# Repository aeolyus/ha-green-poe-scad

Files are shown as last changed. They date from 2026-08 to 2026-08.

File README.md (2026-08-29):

# Home Assistant Green + TP-Link PoE Splitter — 10-inch 1U mount

GitHub Pages site: <https://aeolyus.github.io/ha-green-poe-scad/>

Designed for:

- DeskPi/GeeekPi RackMate T2 12U, 10-inch rack
- Home Assistant Green (official 112 × 112 × 32 mm nominal envelope; physical unit measured 111.13 mm across the bottom, 107.95 mm across the top plateau, and 33.34 mm tall)
- TP-Link TL-PD30G-M2 2.5G PoE+ splitter (80.8 mm published overall length; the revised physical measurements are a 67.47 × 48.42 mm top plateau, 53.98 mm maximum width, 24.61 mm total height, and an 18.26 mm straight side band)
- Bambu Lab X2D

The current user-selected first print is **rear cable entry, 60 mm cable-friendly splitter setback, bottom-aligned rounded vent-frame friction cages, two hollow lower box bridges, two sloped upper hollow-box ties, a plain front with no logo, an open LED viewing aperture, and integrated dovetail receivers with the gates optional**. Use `one_piece_rear_cable_friendly_unified_frame_dovetail_ready.3mf` or `.stl`; the separately printed gate plate is not required for the first fit check. The earlier no-upper-tie and no-dovetail files remain available as comparisons.

Smooth continuous tray walls target a light 0.10 mm-per-side friction fit around the physically measured 111.13 mm lower footprint, then follow the measured inward taper beginning 6.35 mm above the bottom and ending at the 107.95 mm top plateau. Low front/rear stops resist sliding without localized ribs, tabs, or clips. The original 3 mm ventilated honeycomb is translated upward so its top is the normal 9.025 mm device seating plane; the open space below replaces the former four riser columns without filling the tray solid. Annular lands preserve the optional factory screw-hole locations. The Green floor, TP-Link floor, and connecting bridge all share this height, and everything remains fused into the mount. Two hollow 8 mm-high box beams now replace the earlier one-sided L-flanges between the cages. Four longitudinal L-section rails continue the TP-Link cage's upper-left, upper-right, lower-left, and lower-right corners into the faceplate. Their horizontal flanges remain flush with the cage floor and roof, while their vertical flanges stay outside the device envelope. This edge-distributed frame resists sag and twist without center bars, raised internal ridges, permanent triangular braces, or cable-path interference. Any desired support beneath the splitter cage can instead be generated and removed by the slicer.

All device ports face the rear. The TP-Link splitter sits straight on the left with its POWER+DATA IN port toward the rack rear. Its cradle follows the enclosure's symmetric 2.78 mm top and bottom bevel traversals, maintains a conservative 0.05 mm-per-side fit through the profile, and uses four low corner stops that leave both connector centers open. Its LAN/DC outputs face the front internally, and both short jumpers route through the open lane between the two trays before reaching the Green's rear ports.

The front is solid, word-free, logo-free, and has no decorative vents. Its outside corners and exposed tray edges are rounded. Cooling remains open where it matters: the Green's top is unobstructed, the raised 15 mm-pitch Green honeycomb supports it directly, and the narrower splitter shelf uses a 10 mm-pitch honeycomb inside its friction walls. The exposed triangular tray braces remain removed.

The 15 mm Green pattern is in the same visual scale as the linked UCG-Fiber rack mount and slightly finer than the larger cells visible on the linked USW-Lite-8 PoE enclosure. The TP-Link uses smaller cells because its clear shelf width is only about 42 mm; repeating the 15 mm grid there would leave too few load-sharing junctions.

The interactive viewer retains the front-Ethernet, alternate support, logo, shutter, other retention, and ventilated-enclosure studies for comparison. They are not the selected production edition. The ventilated 1U chassis remains viewer-only and is off by default.

## LED window

The production face uses a clean open aperture so the Green's LEDs remain directly visible. It has no lens, actuator slot, rear shutter pocket, retainer, or moving blade. The 8 mm-high aperture is centered on the physically measured illuminated band: 3.175 mm (4/32 in) above the Green's bottom and 19.05 mm (3/4 in) below its top. Its horizontal center now follows the measured 111.125 mm enclosure body rather than the older clearance envelope. The earlier translucent insert and captive shutter remain optional comparison parts.

The former captive-shutter mechanism remains only as a clearly named optional comparison export and as a viewer toggle. Likewise, the optional logo study is not cut into the canonical plain face.

## Cable routing and length check

The interactive preview includes three non-printing cable mockups:

- Incoming PoE patch lead from the rack rear to TP-Link POWER+DATA IN
- Internal Ethernet jumper from TP-Link LAN OUT to the Green
- DC jumper from TP-Link DC OUT to the Green

The production splitter setback is not determined by the incoming PoE lead. Its LAN/DC outputs face the front, so the open space in front of the body gives ordinary straight molded plugs room to exit and turn into the center lane. Moving the splitter forward makes the mount shallower, but it lengthens both internal jumpers and tightens their bend radius.

The updated mockups use a conservative 25 mm external straight-RJ45 boot envelope, Ubiquiti's published 21 mm minimum bend radius for its current patch cable, a 22 mm straight DC plug envelope, and rounded cable turns. These are precomputed static clearance routes—not an interactive physics simulation—and are planning envelopes rather than exact geometry for every cable Richard owns.

The webpage compares three side-by-side rear-entry TP-Link placements, one bottom-aligned unified-frame study, one centered-stacked TP-Link study, three front-Ethernet editions, and one SICSOLINK cable-routing mockup:

- **Compact, 35 mm setback:** 32 mm / 1.26 in from the panel's inside face to the splitter, leaving about 7 mm / 0.28 in after the modeled 25 mm boot; the collision-aware orange mockups require approximately 3.7 mm Ethernet and 7.6 mm DC bend radii, so this remains a visual comparison
- **Balanced, 47.5 mm setback:** 44.5 mm / 1.75 in of inside clearance, leaving about 19.5 mm / 0.77 in after the modeled boot; Richard's actual flexible cable was comfortable at this spacing, although the conservative generic Ethernet mockup remains orange because it targets a larger 21 mm bend radius
- **Cable-friendly, 60 mm setback:** current printable layout; 57 mm / 2.24 in of inside clearance leaves about 32 mm / 1.26 in after the modeled boot, and separate cable lanes preserve the full 21 mm Ethernet and 10 mm DC bend radii
- **Bottom-aligned unified frame, 60 mm setback:** current user-selected print; both cages share the same floor, two hollow lower box bridges join their bases, and two sloped upper hollow-box ties join their unequal roof heights
- **Centered stacked:** viewer-only study with the Green centered on the panel and the TP-Link rotated 90° directly behind it; both sit on the 9.025 mm unified deck, the printed depth is 202.4 mm / 7.97 in, and the side-facing LAN port permits a full-radius R21 turn to the Green
- **Front Ethernet — center gap, 60 mm setback:** the jack sits between the plain left face area and LED window while three layered cable paths preserve the modeled bend radii without increasing printed depth
- **Front Ethernet — HA right, 60 mm setback:** the jack sits physically to the right of the Green, while a full-radius PoE route loops behind the devices; this is a one-piece-only edition because the keystone occupies the detachable right-ear joint zone
- **Front Ethernet — left, 89 mm setback:** alternate jack in the left face area; the splitter moves 29 mm rearward so the straight PoE jumper can rise over it safely
- **SICSOLINK rear-angle:** viewer-only comparison using the existing splitter's seller-stated 180 mm captive leads; the visible routes consume about 165–170 mm and leave roughly 10–15 mm tolerance

The collision-aware internal Ethernet routes are approximately 370 mm across the three TP-Link positions before service slack. A 0.3 m / 1 ft lead is too short once ordinary straight plugs and real bends are included. Use a 0.5 m / roughly 20-inch patch lead. Ubiquiti's current line offers 0.4 m rather than 0.5 m; that leaves little service slack, while a 1 m lead can be looped at the cable-management points.

The corresponding straight-DC routes are approximately 250–275 mm before service slack. A 10-inch lead is too tight for the shallower comparisons; 12 inches / 300 mm is the safe general target and is the likely range of the bundled TP-Link jumper based on the unboxing, though TP-Link does not publish its length. A right-angle DC cable is not required because the RJ45 remains the limiting connector.

For the incoming PoE lead from an adjacent patch-panel coupler, start with a 1 ft cable. Use 0.5 m if the patch panel is more than roughly one rack unit away or if you want a service loop; that run depends on the actual rack-unit spacing and is not assigned an exact length by the viewer.

Each optional front-entry edition needs one additional internal Ethernet jumper from the rear of its feed-through keystone to TP-Link POWER+DATA IN. The modeled tip-to-tip lengths and practical cable choices are:

| Front jack location | Keystone → TP-Link route | Practical cable | Other internal leads |
| --- | ---: | --- | --- |
| Center gap | about 331 mm | 0.4 m minimum; 0.5 m preferred | TP-Link LAN → Green is about 356 mm, so use 0.5 m. DC is about 286 mm; 300 mm is possible but tight, and 350 mm is safer. |
| HA right | about 349 mm with the full 21 mm RJ45 bend | 0.4 m minimum; 0.5 m preferred | Uses the cable-friendly 60 mm splitter-to-Green lanes: use 0.5 m Ethernet and approximately 300–350 mm DC. |
| Left | about 266 mm | 0.4 m minimum; 0.5 m preferred | Use 0.5 m Ethernet and approximately 300 mm DC so ordinary straight plugs retain service slack. |

The center-gap cable envelope reaches about 213.6 mm rack depth; the left reaches about 218.3 mm, both within the T2's nominal 240 mm envelope. The HA-right route also remains within that envelope but deliberately makes a broad rear loop instead of forcing a tight turn. All three editions need a standard Cat6/6A female-to-female keystone coupler. Print `keystone_fit_test.stl` first because latch and body dimensions vary slightly between vendors.

For this rack, rear entry is the selected production layout: it keeps the front visually clean, uses one fewer coupler and internal cable, and gives simpler service access from the patch-panel side. Front entry remains useful as a comparison if you expect frequent troubleshooting or want to repatch without reaching behind the rack.

TP-Link lists a power cord in the box, and an independent unboxing clearly shows a male-to-male barrel jumper. TP-Link does not publish its exact length, barrel dimensions, or polarity. Try that supplied straight lead first. Before connecting the Green, set the selector to 12 V and verify both fit and center-positive polarity with a meter. If a replacement is needed, use a verified 12-inch straight-through lead whose Green end is 5.5 × 2.1 mm and whose current rating is at least 2 A.

Status: both rounded-cage device fits are physically validated as snug. The user-selected bottom-aligned unified-frame STL is closed two-manifold geometry and Bambu Studio reports it as manifold; its new upper ties still need this first full physical print. `assembly.stl` remains a multi-body reference file rather than a print target. The optional dovetail gate remains coupon-gated and does not need to be printed for the first fit check.

## Interactive preview

Open `viewer/interactive_viewer.html` through the included static-site layout and choose the splitter, side-by-side or centered-stacked arrangement, rear/front Ethernet entry, applicable spacing or front-jack position, retention, and optional protection. Those decisions map to nine modeled layouts: Compact, Balanced, Cable-friendly, Bottom-aligned unified frame, Centered stacked, Front–center gap, Front–HA right, Front–left, and the angled SICSOLINK cable example. Centered stacked and SICSOLINK are viewer-only studies. You can rotate, zoom, or jump between front, rear, top, perspective, retention-detail, and LED-window views. The hosted copy loads sibling GLBs to keep the initial HTML near 1 MB; `scripts/build.sh html` can regenerate an embedded single-file offline copy. Both forms record selections in the URL hash so a configuration can be bookmarked or shared.

The default view matches the active print: TP-Link, rear Ethernet, 60 mm cable-friendly setback, the bottom-aligned unified cage frame, integrated dovetail receivers with the gates optional, open trays with no chassis, no logo, no shutter hardware, visible simulated LEDs, and auto-rotation off. The comparison controls can still show the alternate supports, logo, captive shutter, front-entry layouts, other retention studies, and ventilated chassis. Those toggles do not change which files are canonical.

The **Retention** controls compare the selected integrated friction tray with the earlier M3-screw baseline and other studies. **Hybrid top clips · Green + PoE** keeps the Green's fixed/releasable catch arrangement, while the TP-Link now uses four mirrored rigid catches grown directly from continuous mini walls with no relief cuts or spring tongues. **Rounded vent-frame cages · Green + PoE** is the current aesthetic prototype preference: a rear-loading design inspired by the UCG-Fiber, USW-Lite, and Mauker Chromebox enclosure patterns, with honeycomb floors and 1.6 mm roofs meeting thick rounded side frames around one long capsule vent beside each device. The front stops remain and the rear stays open for insertion and cabling. Both cages keep one snug profile from front to rear, with square rear seams so their roofs, floors, and walls finish flush. Physical coupons now validate a snug fit for both devices: the Green uses 0.30 mm side and 0.10 mm roof clearance, while the TP-Link uses its proven 0.10 mm side and 0.05 mm roof clearance. The Green roof finishes at 44.0625 mm—0.3875 mm below the exact 44.45 mm panel top. **Vent-frame cages + padless dovetail gates** adds separately printed optional rear H-gates while retaining the same friction-fit cages as the primary retention. Their straight vertical tracks are buried inside locally thickened rear sidewall ends, and each H-frame seats in a matching shallow pocket so its rear face finishes flush with the cage. One smooth beveled lower beam replaces the former individual pads and sits 0.05 mm behind the device's solid lower rear face. A thin 0.8 mm stepped cap covers the gate pocket and beam-travel opening from above, leaving only a 0.02 mm separation so the roof reads as continuous while the gate remains a separate printable part. The central connector field remains open. The final 7 mm of rail travel wedges to a nominal line fit so the gate does not lift freely. Disconnect rear cables before sliding a gate. The gates need approximately 38 mm above the Green and 25 mm above the TP-Link during installation/removal, so service them before mounting another rack unit immediately above. The complete dovetail-ready one-piece mount and a separate two-gate plate are exported, but the gate sliding fit remains coupon-gated and physically unvalidated. The rounded cage dimensions themselves are already physically validated.

The support selector switches among four complete, mutually exclusive friction-tray meshes without reloading the GLB. **Unified raised deck** is selected: it lifts the original thin 3 mm honeycomb directly to the seating plane and leaves the volume below open. **Four pads** retains the earlier low floor and four raised lands; **Full honeycomb** fills the complete lattice and perimeter up to the seating plane; **Open frame** replaces the floor with a perimeter, two transverse load paths, a center spine, and four lands. Every version includes the same fused friction walls and low stops, with the rear center open for ports and cable service.

The comparison models do not replace tolerance coupons, material-specific clearance tuning, or a physical pull/rattle test. The unified raised-deck geometry is printable but still needs that physical validation because this is a new design.

The **Optional protection** control compares the default open tray with a ventilated full-width 1U chassis. The chassis adds a removable perforated top-and-side cover plus a low guide frame, enclosing the complete assembly while keeping the rear open for cables. With the exact 44.45 mm panel height, its 0.8 mm roof underside retains 1.0875 mm nominal clearance over the measured Green. It remains viewer-only until the enclosure assembly and cable access are physically validated. The chassis control is disabled for the above-device captive-strap, X-cage, and ventilated-sleeve concepts because those mechanisms consume the same roof space. It is off in existing links unless `protection=airframe` is selected.

### Static browser customizer

`customizer/index.html` provides a guided static-site configurator with the
interactive 3D model embedded beside the controls. When served
over HTTP(S), it lazily loads a vendored OpenSCAD WebAssembly worker, generates
the selected geometry locally, validates the binary STL, and offers both STL
and deterministic geometry-only 3MF downloads. From this directory, run
`python3 -m http.server 8000`, then open
`http://localhost:8000/customizer/`. Configuration and preset export still
work when the HTML file is opened directly, but browsers block module workers
under `file://`. Review `customizer/vendor/README.md` before public distribution
of the experimental GPL-2.0 runtime.

The cable models use straight—not right-angle—RJ45 and DC plugs. Orange internal cables identify bend-radius violations; normal blue/black cables meet the modeled envelope. When visible, the window simulates the Green's steady white power light, irregular green activity, and a two-flash yellow heartbeat; timing is illustrative rather than a diagnostic code. Gold three-dimensional rulers use 10 mm ticks, and a compact viewport overlay labels the exact 254 mm panel width, exact 44.45 mm / 1.750 in panel height, layout-specific printed depth, and panel-to-splitter clearance in both millimeters and inches. The viewer depicts the one-piece faceplate, so it has no detachable-ear joining bosses. Each of the nine layouts has two GLBs—shutter comparison and open-window/no-shutter—for 18 primary comparison models. Every applicable GLB contains the standard tray, all four mutually exclusive friction-tray meshes, the other retention overlays, and its layout-specific optional airframe at the same normal Green/LED coordinates, so switching retention, support style, or protection does not reload or reposition the model. The side-by-side TP-Link layouts include the dovetail prototype; the incompatible centered-stacked and SICSOLINK layouts disable it. The no-shutter GLBs omit the insert and shutter meshes entirely, leaving the bare aperture. `viewer/home-assistant-green-rack-preview.glb` is the cable-friendly open-window alias; `viewer/home-assistant-green-rack-preview-no_shutter.glb` is retained for compatibility, and `viewer/home-assistant-green-rack-preview-with_shutter.glb` is explicit.

The colored Home Assistant Green, TP-Link splitter, connector faces, and cables in these preview files are dimensional mockups only and are not part of the printable plate.

The viewer is a hand-built HTML page using Google's open-source `<model-viewer>` web component (which uses Three.js internally). Python and `trimesh` assemble the colored GLBs from OpenSCAD exports. The local offline build can embed those GLBs directly; `scripts/prepare_static_site.py` rewrites them to relative URLs for faster GitHub Pages loading.

## Parts

- `one_piece_rear_cable_friendly_unified_frame_dovetail_ready.stl` / `.3mf` — current user-selected one-piece print: bottom-aligned validated friction cages, two hollow lower bridges, two sloped upper hollow-box ties, and integrated receivers for optional separately printed dovetail gates
- `one_piece_rear_cable_friendly_unified_frame_no_dovetail.stl` / `.3mf` — the same tied cage frame without the optional dovetail receiver geometry
- `one_piece_rear_cable_friendly_vent_frame_no_dovetail.stl` / `.3mf` — earlier one-piece comparison with the physically validated rounded Green and TP-Link cages but no sloped upper ties or dovetail hardware
- `one_piece_rear_cable_friendly_vent_frame_dovetail_ready.stl` / `.3mf` — one-piece 254 mm-wide mount with the same friction cages plus integrated rear dovetail receivers; the devices remain friction-retained when no gates are installed
- `dovetail_gates_optional_plate.stl` / `.3mf` — optional second print containing the Green and TP-Link rear gates, both already resting on their broad rear faces
- `x2d_plate_rear_cable_friendly_vent_frame_no_dovetail.stl` / `.3mf` — safer split alternative containing the vent-frame core and both detachable ears as three faceplate-down objects
- `core.stl` — canonical split-core mount: rear entry, unified raised friction deck, plain face, and open LED aperture
- `one_piece.stl` / `.3mf` — the same canonical mount as one 254 mm-wide part, without detachable ears or rear joining bosses
- `x2d_plate.stl` / `.3mf` — canonical split core and both ears nested for the X2D dual-nozzle area
- `left_ear.stl` / `right_ear.stl` — detachable rack ears for `core.stl`
- `led_insert_optional.stl` and `led_fixed_window_kit_optional.stl` / `.3mf` — optional self-retaining translucent insert comparison
- `friction_fit_coupon.stl` / `.3mf` — regenerated smooth-wall channels at 0.25, 0.30, and 0.35 mm interference per side around the newly measured 111.125 mm bottom. The earlier near-perfect result used the superseded 109.5375 mm estimate and is no longer valid; test these in order and use the first one that holds without scuffing.
- `green_hybrid_clip_coupon.stl` / `.3mf` — one compact full-height Green spring-catch gauge. Its smooth single-piece profile follows the measured taper into a 1.4 mm bearing land with 1.2 mm nominal top overlap, a 0.8 mm shoulder, and a 0.4 mm leading tip. With the revised physical height it reaches 43.89 mm, leaving about 0.56 mm below the exact 44.45 mm panel top; add a 5 mm slicer brim.
- `splitter_fit_coupon.stl` / `.3mf` — three short open-ended smooth-wall test channels at 0.00, 0.05, and 0.10 mm interference per side for the TP-Link body; use the least aggressive level that holds before committing to its full-length friction cradle
- `splitter_hybrid_clip_coupon.stl` / `.3mf` — one compact open-frame TP-Link section with four-way-symmetric rigid ramps grown directly from continuous side walls, 1.4 mm bearing lands, 1.2 mm nominal top overlap, zero nominal top gap, 0.8 mm shoulders, and 0.4 mm leading tips; use it to confirm that the complete wall can flex enough for installation before printing the rack
- `hybrid_clip_coupon.stl` / `.3mf` — the single print containing both compact top-clip gauges, about 9.7 g of PETG total; regenerate or re-download it whenever the clip geometry changes
- `green_vent_frame_coupon.stl` / `.3mf` and `splitter_vent_frame_coupon.stl` / `.3mf` — separate 5 mm-deep solid rear perimeter bands from the exact rounded Green and TP-Link cages. The Green coupon keeps its accepted height and now has 0.30 mm clearance on each side; the TP-Link keeps its prior side fit and lowers only the flexible roof by 0.05 mm. At this depth the crop ends before the floor, roof, or side-wall honeycomb openings begin, and both parts are already oriented with their insertion faces on the build plate.
- `vent_frame_coupon.stl` / `.3mf` — the recommended low-material rounded-cage fit test containing both production-derived solid bands as separate objects; approximately 184.3 × 38.04 × 5 mm and 7.4 g of PETG by mesh volume
- `dovetail_rail_coupon.stl` / `.3mf` — a six-piece rail-and-H-gate clearance test for the viewer-only dovetail retention branch. One, two, and three marker holes identify 0.00, 0.05, and 0.10 mm final-wedge clearances; validate sliding, seated grip, and deliberate removal before considering a complete gated mount.
- `assembly.stl` — reference assembly only; print the separate parts above
- `fit_test.stl` / `.3mf` — general device-clearance check

Clearly named optional exports:

- `*_legacy_screw_tray.*` and `green_spacer*_legacy_screw_tray.*` — prior four-screw Green tray fallback
- `core_with_logo.*`, `one_piece_with_logo.*`, `x2d_plate_with_logo.*`, `logo_inlay_optional.stl`, and `one_piece_logo_inlay_optional.stl` — optional branded-face study; the inlay only fits a matching `_with_logo` mount
- `core_with_shutter.*`, `one_piece_with_shutter.*`, `x2d_plate_with_shutter.*`, and `led_shutter_*_optional.*` — optional captive-shutter study
- `*_front_ethernet_right.*`, `*_front_ethernet_left.*`, and `one_piece_front_ethernet_far_right.*` — optional front-entry comparisons, all otherwise inheriting the unified-raised-deck/plain-face/open-aperture defaults
- `keystone_fit_test.stl` / `.3mf` — front-keystone latch coupon
- The HA-right front-entry comparison is one-piece-only because its keystone occupies the detachable right-ear joint zone

Viewer and render artifacts:

- `renders/assembly_preview.png` — layout preview with translucent device mockups
- `viewer/home-assistant-green-rack-compact.glb` — 35 mm setback comparison mockup
- `viewer/home-assistant-green-rack-balanced.glb` — 47.5 mm setback comparison mockup
- `viewer/home-assistant-green-rack-unified_roof-no_shutter.glb` — GLB used by the production-default viewer state
- `viewer/home-assistant-green-rack-stacked_center.glb` — viewer-only centered Green with a transverse TP-Link directly behind it
- `viewer/home-assistant-green-rack-front_ethernet_right.glb`, `viewer/home-assistant-green-rack-front_ethernet_far_right.glb`, and `viewer/home-assistant-green-rack-front_ethernet_left.glb` — center-gap, HA-right, and left front-keystone mockups with their internal cabling
- Every viewer layout has both a shutter comparison GLB and a paired `-no_shutter.glb` bare-aperture GLB with no lens mesh
- `viewer/home-assistant-green-rack-front_ethernet.glb` and its no-shutter counterpart are compatibility aliases of the center-gap GLBs
- `viewer/home-assistant-green-rack-sics_angled.glb` — viewer-only angled SICSOLINK mockup showing its captive cable routing
- `viewer/viewer_green_tray_friction_raised.stl`, `viewer/viewer_green_tray_friction_pads.stl`, `viewer/viewer_green_tray_friction_full.stl`, and `viewer/viewer_green_tray_friction_skeletal.stl` — mutually exclusive complete friction-tray meshes for Unified raised deck, Four pads, Full honeycomb, and Open frame support; each includes the fused walls and stops
- `viewer/viewer_retention_hybrid_clips.stl` — viewer-only combined prototype containing the complete four-pad Green top-clip tray plus TP-Link replacement side walls with four mirrored rigid catches
- `viewer/viewer_retention_ventilated_sleeves.stl` — layout-specific rear-loading sleeve study with aligned raised honeycomb floors and thick rounded side frames around large capsule vents; no riser columns, springs, or relief slots
- `viewer/variants/*/viewer_enclosure_airframe.stl` — viewer-only ventilated 1U chassis study; it is not part of the printable production files

The selected one-piece vent-frame file is 254 × 44.45 × 143.7 mm in its supplied faceplate-down orientation and is approximately 120 g by PETG mesh volume. It nominally fits the X2D's 256 mm main-nozzle area with only 1 mm per side; center it carefully and do not use a brim. The X2D profile gives nozzle 1 the full X=0–256 mm area and nozzle 2 the X=20.5–256 mm area. Therefore the complete part does not need to fit inside the 235.5 mm overlap when nozzle 2 is used only for localized support interfaces: the PoE/bridge region sits at approximately X=28–88 mm on a centered plate and remains reachable by both nozzles. Keep the PETG model on nozzle 1 and any PLA support interface on nozzle 2. The safer split vent-frame plate is 220 × 94.45 × 143.7 mm, contains three objects, and is approximately 130 g because of the ear-joining bosses. The printed mount and modeled cable exits stay within the RackMate T2's approximately 240 mm internal depth.

## Hardware

- 4 × M3 × 8 mm screws for attaching the ears to the center section (preferred; M3 × 10 mm can work but leaves less front skin)
- 4 × #10-32 × 5/16 rack screws supplied with the RackMate T2
- Optional small zip ties for the short internal DC/LAN cable-management slots only; there are no Green-device zip-tie slots
- Any front-entry edition: 1 × Cat6/6A female-to-female keystone coupler and 1 × 0.5 m internal Ethernet patch cable

The Green needs no mounting screws in the selected friction tray; leave its factory bottom screws untouched. The M3 × 8 screws enter from the rear and only join the optional printed ears to the printed center. They self-tap into 2.6 mm pilot holes, so do not overtighten. They and the rear joining bosses are absent from `one_piece.stl`. The T2's pre-threaded rack rails officially use #10-32 screws, not M6 cage-nut hardware.

## Suggested print settings

- Material: white PETG (preferred) or ASA
- Layer height: 0.20 mm
- Walls: 4
- Top/bottom shells: 5
- Infill: 25–30% gyroid
- Supports: none for the core; use build-plate-only support beneath the two rear tongues on each ear
- Print `core.stl` faceplate-down: rotate it so the broad front face lies on the build plate. The raised decks then grow edge-on from the panel instead of beginning 6.025 mm above the bed.
- The selected `one_piece_rear_cable_friendly_unified_frame_dovetail_ready` files are already faceplate-down. Center the part and do not add a brim. Use nozzle 1 for the PETG model. The lower boxes and upper ties each begin as a roughly 16 mm bridge between already-established cage walls; PETG should normally bridge that distance, but the X2D can use localized PLA support interfaces there if your preview flags them. The support region remains inside nozzle 2's X=20.5–256 mm reach.
- The same orientation applies to optional comparison mounts and the HA-right one-piece file
- Ear and LED-insert STLs are already exported face-side down; enable support for the ear tongues

The supplied 3MF is geometry-only, not a pre-sliced Bambu project. In Bambu Studio, split it into objects and use normal/snug build-plate-only support on the ears rather than broad tree supports. A brim is normally unnecessary; a wide brim may join the nested pieces.

The production LED window is intentionally left open, so there is no lens, shutter blade, or retainer to print or assemble. The optional translucent insert can still be generated for comparison if dust protection is preferred later.

For the current friction baseline, print `friction_fit_coupon.stl` and `splitter_fit_coupon.stl`. If top clips are preferred, print only `hybrid_clip_coupon.stl` or `.3mf`; it places the selected Green and TP-Link gauges together without joining their roots. Use PETG or ASA, 0.20 mm layers, and 4–5 walls. Print the Green gauge tray-down with a 5 mm brim; orient the TP-Link gauge on its open Y/end face so its layers match the intended faceplate-down production print. The TP-Link coupon intentionally has no spring slots: tuck one edge under its rigid catches, then rock the opposite edge into place and confirm the continuous walls flex without whitening or cracking.

The rounded vent-frame coupons have now passed physically for both devices. Print the complete no-dovetail mount using the same printer, material, wall count, and dimensional-compensation settings as those successful coupons. The completed mount still needs a first-article pull/rattle check because its full-length cages are stiffer than the 5 mm gauges.

## Electrical safety

Home Assistant Green requires 12 V DC, 1 A, center-positive through a 5.5 × 2.1 mm barrel connector. The TP-Link provides selectable 12/9/5 V at up to 2 A and must be set to 12 V before any cable is connected. TP-Link does not publish the included cord's barrel dimensions or polarity, so verify center-positive output before connecting it to the Green; reverse polarity or the wrong selector setting can damage the Green.

## Purchase list and observed price

- [TP-Link TL-PD30G-M2](https://www.amazon.com/dp/B0F4CR925P) — $19.99 observed on 2026-08-25; includes the power cord
- Existing 0.5 m / roughly 20-inch UniFi or Monoprice patch cable for TP-Link LAN OUT → Green; 1 ft is too short with ordinary straight plugs
- Existing 1 ft patch cable for an adjacent PoE patch-panel coupler → TP-Link POWER+DATA IN; use 0.5 m for a larger RU separation or service loop
- 4 × M3 × 8 mm screws for the printed ears, if not already on hand

For the recommended rear-entry edition, no extra keystone coupler is required when the existing patch panel already has PoE-capable feed-through couplers. With existing patch cables and RackMate screws, the new electrical hardware total is $19.99 plus tax. Any optional front-entry edition adds the price of one female-to-female keystone and a 0.5 m internal jumper. A separate PoE injector is not needed when the source is already a standards-compliant PoE/PoE+ switch port.

## Source and export

The parametric source is `ha_green_rack.scad`. Example exports:

```sh
# Canonical production geometry inherits the source defaults.
openscad -o exports/core.stl -D 'part="core"' ha_green_rack.scad
openscad -o exports/one_piece.stl -D 'part="one_piece"' ha_green_rack.scad
openscad -o exports/x2d_plate.stl -D 'part="x2d_plate"' ha_green_rack.scad
openscad -o exports/led_insert_optional.stl -D 'part="led_insert"' -D 'led_window_insert_enabled=true' ha_green_rack.scad
openscad -o exports/friction_fit_coupon.stl -D 'part="friction_fit_coupon"' ha_green_rack.scad
openscad -o exports/green_hybrid_clip_coupon.stl -D 'part="green_hybrid_clip_coupon"' ha_green_rack.scad
openscad -o exports/splitter_fit_coupon.stl -D 'part="splitter_fit_coupon"' ha_green_rack.scad
openscad -o exports/splitter_hybrid_clip_coupon.stl -D 'part="splitter_hybrid_clip_coupon"' ha_green_rack.scad
openscad -o exports/hybrid_clip_coupon.stl -D 'part="hybrid_clip_coupon"' ha_green_rack.scad
openscad -o exports/green_vent_frame_coupon.stl -D 'part="green_vent_frame_coupon"' ha_green_rack.scad
openscad -o exports/splitter_vent_frame_coupon.stl -D 'part="splitter_vent_frame_coupon"' ha_green_rack.scad
openscad -o exports/vent_frame_coupon.stl -D 'part="vent_frame_coupon"' ha_green_rack.scad
openscad -o exports/dovetail_rail_coupon.stl -D 'part="dovetail_rail_coupon"' ha_green_rack.scad

# Clearly named optional comparisons.
openscad -o exports/one_piece_legacy_screw_tray.stl -D 'part="one_piece"' -D 'green_tray_style="standard"' ha_green_rack.scad
openscad -o exports/one_piece_with_logo.stl -D 'part="one_piece"' -D 'face_logo_enabled=true' ha_green_rack.scad
openscad -o exports/one_piece_logo_inlay_optional.stl -D 'part="one_piece_logo_inlay"' -D 'face_logo_enabled=true' ha_green_rack.scad
openscad -o exports/one_piece_with_shutter.stl -D 'part="one_piece"' -D 'led_shutter_enabled=true' ha_green_rack.scad
openscad -o exports/led_shutter_kit_optional.stl -D 'part="led_shutter_kit"' -D 'led_shutter_enabled=true' ha_green_rack.scad

# Optional front-entry comparison; all unspecified choices remain production defaults.
openscad -o exports/one_piece_front_ethernet_right.stl -D 'part="one_piece"' -D 'front_ethernet_enabled=true' -D 'front_keystone_side="right"' -D 'splitter_y_override=60' ha_green_rack.scad
openscad -o exports/one_piece_front_ethernet_far_right.stl -D 'part="one_piece"' -D 'front_ethernet_enabled=true' -D 'front_keystone_side="far_right"' -D 'splitter_y_override=60' ha_green_rack.scad
openscad -o exports/keystone_fit_test.stl -D 'part="keystone_fit_test"' ha_green_rack.scad
```

To regenerate the canonical production files, named comparison exports, PNGs, GLBs, and embedded offline viewer in one pass, run `bash scripts/build.sh full` in an environment containing OpenSCAD, Python, NumPy, and trimesh. One Nix invocation is:

```sh
nix shell --impure --expr 'with import <nixpkgs> {}; buildEnv { name = "ha-rack-build"; paths = [ openscad-unstable (python3.withPackages (ps: [ps.trimesh ps.numpy])) ]; }' -c env OPENSCAD_BIN=openscad-unstable bash scripts/build.sh full
```

STL builds try OpenSCAD's Manifold backend first and validate the binary STL
before replacing an existing artifact. A failed export, open edge, over-shared
edge, or inconsistent winding automatically retries with CGAL. The large
printable 3MF variants explicitly use CGAL because the current Manifold 3MF
export can retain zero-area triangle fragments; PNG and small accessory exports
keep OpenSCAD's normal rendering behavior. Outputs are replaced atomically.
Build logs show the selected backend, elapsed time, and fallback reason. Set
`OPENSCAD_BIN` to use a different OpenSCAD executable; older builds without
backend selection run through their normal CGAL path.

For faster iteration, use the incremental wrapper after at least one full build:

```sh
# HTML/JavaScript or option-copy changes only; no OpenSCAD, NumPy, or trimesh.
bash scripts/build.sh html

# Repack existing STL geometry into GLBs and refresh the HTML.
bash scripts/build.sh glb

# Rebuild one layout's viewer geometry, both shutter states, GLBs, and HTML.
bash scripts/build.sh viewer cable_friendly
bash scripts/build.sh viewer stacked_center

# Rebuild every layout after changing per-layout geometry such as the optional airframe or TP-Link hybrid clips.
bash scripts/build.sh viewer

# Rebuild a retention concept, then refresh the affected viewer GLBs.
# Hybrid clips are rebuilt separately for every splitter setback.
bash scripts/build.sh retention slide_latch

# Rebuild canonical production files plus clearly named comparisons.
bash scripts/build.sh full
```

`viewer` and `glb` accept multiple variant names; omit them to rebuild every comparison layout. `glb` repacks both shutter states for each selected layout. `retention friction_sleeve` rebuilds all four shared friction support styles plus the centered-layout copies and compatibility alias. Layout-specific retention meshes keep the side-by-side and centered-stacked geometry aligned independently. OpenSCAD viewer jobs run four at a time by default, adjustable with `VIEWER_BUILD_JOBS`. Partial outputs are written to temporary files and moved into place only after a successful build.

`scripts/dovetail_slide_collision.scad` is the regression fixture for the removable rear gate. Export it with `part="__validation_only__"`, `test_device="green"` or `"splitter"`, and a `slide_lift` value. An empty top-level result means the gate clears the cage at that insertion height; `test_target="ports"` checks the same sweep against the modeled connector envelopes.

## Licensing and attribution

Original project code and independently modeled geometry are offered under MIT. The self-contained viewer embeds upstream components under their own licenses: Google `model-viewer` (Apache-2.0), Three.js (MIT), and Lit (BSD-3-Clause).

The M3 hole pattern and spacer dimensions were independently reimplemented from published measurements in [mikkelgj's editable Printables reference](https://www.printables.com/model/1752618-home-assistant-green-10-1u-rackmount-with-keystone), which is offered under CC BY-SA; no mesh or source body is bundled here. The X-cage comparison is an independent photo-based study inspired by [Andsten's MakerWorld 590818 model](https://makerworld.com/en/models/590818-home-assistant-green-poe-splitter-10-rack-mount#profileId-512398), listed as `BY-NC`; no original mesh is copied. The friction-sleeve comparison was reconstructed from public product images and descriptions for [Etsy 4430188404](https://web.archive.org/web/20260207053959/https://www.etsy.com/listing/4430188404/home-assistant-green-10-rack-mount); no seller CAD or mesh was available or redistributed.

## Dimensional references and alternatives

- [Screwless-retention research and coupon plan](screwless-retention-research.md)
- [Home Assistant Green datasheet](https://github.com/NabuCasa/support/raw/refs/heads/main/static/docs/green/Green_v2.0_Datasheet.pdf)
- [Bambu Lab X2D specifications](https://bambulab.com/en/x2d/specs)
- [Ubiquiti UniFi Patch Cable specifications](https://store.ui.com/us/en/category/accessories-cables-dacs/collections/accessories-pro-patch-cables/products/uacc-cable-patch) — source for the modeled 21 mm minimum bend radius; the 25 mm boot projection remains a conservative planning assumption
- [Official DeskPi RackMate printable models and mechanical drawings](https://github.com/DeskPi-Team/3DPrint-Models)
- [Home Assistant Green 10-inch 1U mount with editable STEP/Fusion source](https://www.printables.com/model/1752618-home-assistant-green-10-1u-rackmount-with-keystone) — a good proven-looking alternative, but it does not include this PoE splitter cradle
- [MakerWorld 10-inch Home Assistant Green mount](https://makerworld.com/en/models/1974297-10-inch-rack-mount-for-home-assistant-green#profileId-2123231) — visual reference requested for the icon badge
- [TP-Link TL-PD30G-M2 official specifications](https://www.tp-link.com/us/business-networking/soho-accessory/tl-pd30g-m2/)
- [TP-Link TL-POE10R official specifications](https://www.omadanetworks.com/us/business-networking/omada-accessory-poe-adapter/tl-poe10r/) — the enclosure is nominally the same 80.8/81 × 54 × 24 mm size as the TL-PD30G-M2; the substantive differences are Ethernet speed, PoE class, and output power
- [Simple Icons: Home Assistant](https://simpleicons.org/?q=homeassistant) — SVG geometry used for the badge; Home Assistant is a trademark of Nabu Casa

This model is an independent parametric design. The references above were used to cross-check device envelopes, rack slots, cooling access, and printer fit.

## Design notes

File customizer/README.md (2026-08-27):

# Static browser customizer

This prototype generates validated STL and 3MF files entirely in the browser.
No geometry or configuration is uploaded to a server.

## Run it

Browser mesh generation requires HTTP(S) because it uses an ES-module Web
Worker. From the project root:

```sh
python3 -m http.server 8000
```

Then open <http://localhost:8000/customizer/>.

Opening `index.html` directly still supports configuration, URL sharing,
viewer handoff, JSON export, and OpenSCAD preset export, but browsers block the
mesh worker under `file://`.

## Implemented

- Guided Layout → Retention → Print design → Output choices
- Current production selection as the reset/default state
- Compatibility and physical-fit warnings
- Shareable configuration in the URL hash
- Configuration JSON and OpenSCAD parameter-set downloads
- Copyable desktop OpenSCAD command
- Embedded live 3D preview that follows the form, plus an optional full-viewer link
- Lazy-loaded OpenSCAD WebAssembly generation in a cancellable worker
- Fast Manifold attempt followed by a fresh CGAL fallback when validation fails
- Binary STL validation: finite vertices, distinct triangle vertices, closed
  edge incidence, consistent winding, positive component volume, component
  count, and configuration-aware bounds
- Deterministic geometry-only 3MF packaging with embedded configuration metadata

The first generation loads a 13.9 MB vendored runtime and may use roughly
230 MB of browser memory. The selected one-piece model currently falls back to
CGAL and takes roughly 35–50 seconds on this machine; small coupons often finish
with Manifold in under a second.

## Safety boundaries

The browser validates mesh topology and dimensions but cannot prove physical
fit, cable clearance, material shrinkage, or printer calibration. For the
top-clip option, print `exports/hybrid_clip_coupon.3mf`; it combines the selected
Green and TP-Link gauges in one low-material plate. Custom setback values and
comparison layouts remain test-fit choices.

## Runtime provenance

The local prototype vendors `openscad-wasm@0.0.4`, licensed GPL-2.0. See
`vendor/README.md` and `vendor/COPYING.openscad-wasm`. Its npm artifact lacks a
precise corresponding-source pointer, so self-build the official
`openscad/openscad-wasm` repository at a pinned commit before public hosting.

See `BROWSER_GENERATION.md` for completed architecture and remaining hardening.

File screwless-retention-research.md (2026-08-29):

# Screwless Home Assistant Green retention

Research date: 2026-08-26

## Recommendation

The best current screwless design is the **unified raised direct-friction tray with thin honeycomb**, printed faceplate-down. It stays below the Green, uses no small flexures or separate parts, keeps the top and rear open, and already has integral front/rear stops for cable-pull loads. Reprint its fit coupon because the old result used the superseded 109.5375 mm footprint.

The rounded vent-frame cage remains the preferred enclosed/aesthetic experiment. Its continuous frame provides broad top and bottom capture without small snap features. Physical coupons now validate snug fits for both devices: the Green uses 0.30 mm nominal side clearance with 0.10 mm roof clearance, and the TP-Link uses 0.10 mm side clearance with 0.05 mm roof clearance. Without moving the device or LED opening, the Green's 1.6 mm roof ends at Z=44.0625 mm, leaving 0.3875 mm below the exact 44.45 mm panel outline. The fit profile remains constant from front to rear; square rear seams keep the roof, floor, and side frames flush without a separate flare. The remaining coupon-gated uncertainty is the optional dovetail rail lock, not either device cavity.

The viewer prototype applies the same force-path idea to both devices:

- **Home Assistant Green:** two fixed left catches and two releasable right spring catches follow the measured upper taper, then overlap the clear lid edge by 1.2 mm. Short lower guides locate the measured 111.125 mm base, allow for the official 112 mm maximum cover envelope, and converge to the measured 107.95 mm top plateau.
- **TP-Link:** the bevel-aware cradle opens at the lower bevel, grips only the widest side band, and now uses four mirrored rigid catches grown directly from continuous mini walls. There are no tongue-relief cuts or separate spring regions; both sides use the same ramp/nose geometry and 1.2 mm nominal top overlap.
- **Rounded vent-frame alternative:** two rear-loading device-local cages use honeycomb floors and roofs joined by substantial rounded side frames. Each device receives one long capsule vent per side. Broad lower rails, end blocks, and roof borders follow the structural language of the supplied UCG-Fiber 3MF, the referenced USW-Lite enclosure, and Mauker's Chromebox rack mount while retaining large airflow openings.
- In the hybrid option, existing low front/rear stops take cable-pull loads, so the top catches mainly resist lift and tilt rather than carrying constant preload.
- The catches are short and broad instead of a thin X roof, and they leave the center of both devices open for airflow.
- The revised Green hybrid prototype reaches 43.8875 mm, leaving 0.5625 mm below the exact 44.45 mm panel top.

Physical TP-Link measurements from the unit on hand use 1/32-inch ruler increments: 53.975 mm maximum width (2 1/8 in), a revised 48.41875 mm flat plateau width (1 29/32 in), 24.60625 mm total height (31/32 in), and an 18.25625 mm straight side band (23/32 in). The enclosure is symmetric top-to-bottom, so the remaining height is divided into equal 3.175 mm (1/8 in) vertical bevel traversals. Both plateaus are inset 2.778125 mm (7/64 in) per side. The measured 67.46875 mm length (2 21/32 in) remains modeled as the flat plateau length, not the full housing; TP-Link publishes an 80.8 mm overall length, leaving matching 6.665625 mm longitudinal bevels at each end of both plateaus.

## Evidence from existing designs

- [MakerWorld 883556](https://makerworld.com/en/models/883556-home-assistant-green-wall-mount) uses a slide-in pocket/sleeve with open ports and airflow. It has 294 reported prints and 385 downloads. In a horizontal rack it would still need a positive end latch because gravity no longer retains the device.
- [MakerWorld 2297786](https://makerworld.com/en/models/2297786-wall-mount-din-rail-for-home-assistant-green) uses side rails, compliant S-shaped spring pieces, and end restraints and is shown holding the Green upside down. It proves compliant retention can work, but its glued multipart construction is less attractive for this rack.
- [MakerWorld 452481](https://makerworld.com/en/models/452481-wallmount-for-home-assistant-green), [Printables 691723](https://www.printables.com/model/691723-home-assistant-green-wall-mount), [Printables 680691](https://www.printables.com/model/680691-home-assistant-green-wall-mount), and [Thingiverse 6846821](https://www.thingiverse.com/thing:6846821) use the same broad C-channel family. Downloaded sections measure about 112 mm between side walls and about 104 mm between inward returns: roughly 4 mm of clear-lid overlap per side. That is a rear-slide sleeve dimension, not a suitable snap-over value.
- [Thingiverse 6770609](https://www.thingiverse.com/thing:6770609) uses two side grips and suggests rubber feet to improve retention.
- [Thingiverse 6846821](https://www.thingiverse.com/thing:6846821) uses rounded inward return rails over the clear top edge. The rounded return is stronger and less scuff-prone than a sharp hook.
- [Hive Tech rack mount](https://hivets.au/products/rack-mount-for-home-assistant-green-modular) uses a snug slide-in frame.
- [MakerWorld 590818](https://makerworld.com/en/models/590818-home-assistant-green-poe-splitter-10-rack-mount#profileId-512398) uses an open X-braced cage over the clear lid plus separate removable rear retaining frames. It proves that positive top capture works in a rack orientation, but one commenter reported repeated breakage at thin diagonal-truss nodes. Its license is BY-NC, and the viewer option is an independent dimensional study rather than copied mesh geometry.
- [Etsy 4430188404](https://web.archive.org/web/20260207053959/https://www.etsy.com/listing/4430188404/home-assistant-green-10-rack-mount) is a one-piece open-top pocket with tapered side cheeks and shallow end stops. The listing and [Nexus3D assembly guide](https://nexus3d.co.uk/guides/assemble-10-inch-rack-mounts/) describe a deliberately tight fit, with no visible latch, gate, screw, or upper capture feature.

## Ranked alternatives

1. **Unified raised direct-friction tray** — best overall screwless balance: lowest height, fewest parts, support-free printing, open airflow, and integral fore/aft stops. Its risks are printer-specific interference, scuffing, and long-term PETG relaxation.
2. **Factory screws** — best absolute security and tolerance robustness with no top-height penalty, but slower service and a hardware/overtightening risk.
3. **Low rear-slide C-rails plus captured dovetail gate** — best future positive screwless architecture, but it still needs lower-ledge measurements, port-aware integration, and a rail-clearance coupon.
4. **Slide shoes plus rear latch** — open and support-friendly, but dependent on an unmeasured lower ledge and a fatigue-prone flexure.
5. **Four lower corner cups plus a captive rear gate** — tolerant and well ventilated, but gives less direct uplift capture and adds a moving part.
6. **Rounded vent-frame rear-loading cages** — best aesthetics and broad capture with large vents. The 1.6 mm preloaded roof stays below the exact 44.45 mm faceplate outline, but full-length fit remains sensitive to tolerance and creep.
7. **Light guides plus localized top-edge catches** — open and light with positive lift resistance, but currently over the faceplate outline and dependent on small flexing features plus exact taper assumptions.
8. **Separate sliding sled/cage with a captive rear gate** — robust and replaceable, but costs more filament, interfaces, and service steps.
9. **Rigid rails with TPU anti-rattle pads plus a hard latch** — tolerant and quiet; TPU must not be the only restraint.
10. **Captive TPU or hook-and-loop strap** — dependable but over-height, visually busy, and subject to material creep.
11. **Full X-brace cage plus removable rear cap** — secure, but over-height, heavier, more obstructive to top airflow, and vulnerable at thin diagonal intersections.

Avoid 4 mm-class community return rails in a top-loading design: those dimensions assume the device slides in from an open end. Also avoid friction-only side springs, thin X lattices, magnets, and adhesive/Dual Lock. The Green can use shallow top catches only if their complete height remains below the real rack clearance and a coupon verifies release without whitening or scuffing.

The browser overlays are form and force-path studies, not finished printable mechanisms. Gate captivity, sled receivers, latch flexures, strap hinges/snaps, mating features, and final tolerances still require engineering and physical coupons. TPU pads are anti-rattle aids rather than standalone positive retention.

### Rear dovetail-gate study

The MakerWorld 590818 photographs show separate open rear H-frames dropping vertically into paired channels after each device is inserted from the rear. The rails block straight rear withdrawal and blind bottoms stop downward travel; no separate screw or obvious snap is visible, so the original appears to rely on channel friction and gravity.

An independent stronger branch was prototyped without copying the licensed mesh: separate Green and TP-Link gates use a shared 60-degree dovetail standard, 2.8 mm rail depth, 2.6 mm neck, 5.8 mm head, 0.25 mm running clearance per flank, and a final 7 mm wedge zone closing to a nominal line fit. A 1.2 mm blind bottom stop and top lead-in avoid thin spring tabs; the exposed top bar remains available for deliberate removal. The straight receiver tracks are now buried inside locally thickened rear sidewall ends rather than extended behind the cage. Each H-frame slides through a shallow rear pocket and finishes flush with the cage's rear face while the wider dovetail heads remain captured farther forward in the wall. The revised gate replaces the two anti-rattle pads with one smooth lower crossbeam positioned 0.05 mm behind the device's solid lower rear face. A shallow bevel spans the complete beam rather than concentrating force at small tabs, and one clean rear opening replaces the two narrow pad slots. The central connector field stays open, but cables must be disconnected while sliding the gate. Discrete cage collision checks at 0, 1, 7, 20, and 40 mm of gate lift are empty for both devices; the installed gates also clear the modeled connector bodies. Standalone gate exports are rotated broad rear face down instead of balancing on a 2.4 mm edge. If pursued, first print the rail coupon with 0.00, 0.05, and 0.10 mm final wedge clearances.

Do not add this gate to the direct-friction tray: that tray's integral front and rear stops already carry fore/aft cable loads, so the gate adds parts and connector-side complexity without fixing an unmet failure mode. A captured rear gate becomes useful only for a future low-profile rear-loading C-rail or cage whose main sleeve deliberately permits axial sliding.

## Starting geometry for PETG prototypes

- Green lower guide: 0.20 mm/side nominal interference against the measured 111.125 mm lower footprint, held for only 2.5 mm above the device seat before allowing for the 112 mm maximum cover.
- Green upper clearance: 0.35 mm/side around the published cover envelope.
- Green catches: two per side, 18 mm long; 2.4 mm fixed arms on the left and 2.8 mm spring arms on the accessible right side.
- Green clip coupon: one 3.575 mm-reach screening gauge with a production-height spring root, two rib-supported seating pads, and one smooth X/Z profile joining the root, taper follower, 1.4 mm bearing land, 0.8 mm shoulder, and 0.4 mm minimum leading tip. Under the measured 111.125-to-107.95 mm taper, it overlaps the top face by 1.2 mm.
- Green catch underside: 0.30 mm above the modeled top and follows the 2.4 mm upper taper before reaching its horizontal bearing land. Maximum prototype height is 43.8875 mm.
- TP-Link bevels: symmetric 3.175 mm upper and lower vertical traversals. The plateau is inset 2.778125 mm per side. The rounded cage follows that profile with 0.10 mm side clearance and 0.05 mm roof clearance; the separate legacy/direct tray still retains its own 0.05 mm-per-side friction setting.
- TP-Link clip: four symmetric 14 mm-long rigid catches are fused directly into uninterrupted side walls. Both sides follow the measured 3.175 mm upper inset and use zero nominal top gap for a snug friction/preload fit, a 1.4 mm bearing land, 1.2 mm nominal top overlap, 0.8 mm shoulder, and 0.4 mm leading tip. The whole wall must supply the small installation deflection, so the coupon is required before a full print.
- TP-Link clip coupon: one full-width open-frame section using the exact mirrored production-study catches. Five-millimeter transverse seating bars and six-millimeter root rails prevent the coupon from twisting more easily than the complete tray.
- Rounded vent-frame sleeves: 1.6 mm honeycomb roofs with 5 mm borders and aligned raised 3 mm honeycomb floors. Both device floors and the connecting bridge finish at Z=9.025 mm without separate riser columns. The Green side frames follow the measured 111.125 mm bottom for the first 6.35 mm, then taper continuously to the 107.95 mm top plateau; they use 2.4 mm frame thickness, 0.30 mm nominal side clearance, 0.10 mm roof clearance, one approximately 99.8 × 21 mm capsule opening, and 8 mm end blocks. The TP-Link follows the revised 53.975/48.41875/24.60625 mm bevel profile with 0.10 mm side clearance and 0.05 mm roof clearance, one approximately 72.6 × 13 mm capsule opening, and 7 mm end blocks. Both sleeves keep the same profile front-to-rear and use front-rounded/rear-square outlines so roof, floor, and walls meet flush at the rear. The Green roof ends at Z=44.0625 mm, leaving 0.3875 mm below the exact 44.45 mm panel outline; the TP-Link roof ends at Z=35.28125 mm. Both sleeves omit fixed rear stops for axial loading.
- Rounded vent-frame coupon: an exact 5 mm crop from the solid rear border of each complete cage, including the production floor, side-frame, roof, taper, and bevel contact surfaces but ending before the honeycomb openings begin. The revised Green band is approximately 116.53 × 38.04 × 5 mm and 4.7 g of PETG by mesh volume; the revised TP-Link band is approximately 59.78 × 29.26 × 5 mm and 2.7 g. The combined two-object plate is approximately 184.3 × 38.04 × 5 mm and 7.4 g. The shorter band minimizes material while preserving the critical fit cross-section; because it flexes more readily than the full cage, it is a dimensional screening gauge rather than a final extraction-force test.
- The cable-friendly rounded-frame overlay is approximately 63.4 g of PETG by mesh volume after replacing the low floors and Green riser pads with the unified raised decks. This is the two-device sleeve overlay, not the complete faceplate/mount mass.
- Print in PETG or ASA at 0.20 mm layers with 4–5 walls. Print the Green gauge tray-down with a 5 mm brim. Print the TP-Link gauge on its open Y/end face so its layers match the intended faceplate-down production orientation. The vented-sleeve concept should be printed faceplate-down, matching the supplied UCG-Fiber 3MF.

Design target: at least 25–30 N extraction resistance and 20 N lift/tilt resistance. The Green weighs about 340 g, or 3.34 N statically.

## Measurements needed before the full CAD revision

Official material does not publish the taper cross-section. Measure with calipers if possible:

- maximum width/depth at the dark lower base;
- maximum clear-cover width at the catch height;
- top-face width immediately inside the clear edge;
- height where the lower black base transitions to the clear cover;
- lower-base corner radius;
- flat support areas versus cooling fins;
- port-edge keep-out;
- actual installed clearance above the Green.

If calipers are unavailable, print a short stepped coupon rather than guessing.

For the selected direct-seat friction concept, heat is not the main uncertainty; the Green is a low-power device and the honeycomb remains open. The unresolved issue is mechanical: the public dimensions do not show whether fins, screw bosses, labels, or a perimeter foot are the first underside contact. A shallow underside/rib coupon should therefore verify that the enclosure sits flat and does not rock before generating the complete printable tray.

No complete official Green enclosure CAD was found. The closest device-part reference is the user-made [MakerWorld 1025019 replacement shell](https://makerworld.com/en/models/1025019-home-assistant-green-box), which includes STEP/STL under CC BY-NC-SA 4.0. It can help validate the translucent shell profile but does not model the black heatsink or lower seam required for a precise rail fit.

## Validation sequence

1. Print the combined `vent_frame_coupon.3mf`; it contains mechanically independent, exact 5 mm solid rear-border crops of the Green and TP-Link rounded cages and is already oriented for the intended faceplate-down layer direction.
2. Slide each device into its matching band only far enough to engage the complete constant-clearance profile. Stop if insertion requires excessive force or the frame whitens.
3. Confirm that each device sits flat without rocking, remains snug during a gentle upside-down test, and withdraws without surface scuffing or permanent spreading.
4. If either cage is too loose or tight, adjust only that device's interference and regenerate the same short coupon. Once both pass, generate one complete rounded-cage mount and perform at least 50 insert/remove cycles plus a warm cable-pull test before promoting it to the canonical print.
5. Keep `hybrid_clip_coupon.3mf` as the fallback experiment if the continuous cage proves too sensitive or difficult to service.

## Sources

- [Home Assistant Green specifications](https://www.home-assistant.io/green/)
- [Protolabs snap-fit design guidance](https://www.hubs.com/knowledge-base/how-design-snap-fit-joints-3d-printing/)
- [Xometry FDM design tips](https://xometry.pro/en/articles/fdm-design-tips/)
- [AON3D engineering fits](https://www.aon3d.com/applications/engineering-fits-how-to-design-for-3d-printed-assemblies/)
- [MakerWorld 590818 rack mount](https://makerworld.com/en/models/590818-home-assistant-green-poe-splitter-10-rack-mount#profileId-512398)
- [Mauker ASUS Chromebox 3 rack mount](https://makerworld.com/en/models/2526812-asus-chromebox-3-cn65-10-inch-rack-mount) — visual reference for thick rounded capsule-vent frames; no source geometry reused
- [Archived Etsy 4430188404 listing](https://web.archive.org/web/20260207053959/https://www.etsy.com/listing/4430188404/home-assistant-green-10-rack-mount)
- [Nexus3D product page](https://nexus3d.co.uk/product/home-assistant-green-10-rack-mount/)

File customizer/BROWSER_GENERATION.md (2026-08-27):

# Browser STL/3MF generation plan

## Goal

Turn the current zero-build static form into a static-hosted configurator that can generate a checked STL or 3MF without sending the design or settings to a server.

## Recommended architecture

1. **Configuration UI**
   - Keep this form as the only source of user input.
   - Validate every value against an allowlist and tight numeric bounds.
   - Serialize a versioned configuration and stable hash for sharing and caching.

2. **Geometry worker**
   - Run OpenSCAD compiled to WebAssembly inside a Web Worker so rendering cannot freeze the UI.
   - Mount a pinned copy of `ha_green_rack.scad` in the worker's virtual filesystem.
   - Pass the generated parameter-set JSON to OpenSCAD rather than constructing source code from user text.
   - Start with the small controlled choice set in this prototype. Do not expose arbitrary SCAD expressions.

3. **Validation worker**
   - Parse the STL before enabling download.
   - Require finite coordinates, nonzero triangles, expected bounding-box limits, and closed two-manifold edges.
   - Report the checks in plain language next to the download button.
   - Consider a pinned Manifold WASM build for validation/repair, but reject unexpected repairs instead of silently changing geometry.

4. **Artifact packaging**
   - Offer binary STL immediately after validation.
   - Package 3MF client-side as a standards-compliant ZIP container with model units, object names, and configuration metadata.
   - Keep slicer profiles out of the first release; a geometry-only 3MF is more portable and less likely to imply printer settings were validated.

5. **Caching and responsiveness**
   - Cache successful artifacts in IndexedDB by `source-version + normalized-parameters + output-format`.
   - Debounce edits, but compile only after an explicit Generate action.
   - Show separate queued, compiling, validating, and ready states with elapsed time and a cancel button.
   - Keep the existing prebuilt GLB viewer for instant feedback while the exact mesh compiles.

## Static hosting constraints

- Bundle and pin all JavaScript/WASM assets; avoid runtime CDN dependencies.
- A single-threaded WASM build works on ordinary static hosting. A faster threaded build may require `Cross-Origin-Opener-Policy` and `Cross-Origin-Embedder-Policy` response headers, which some static hosts cannot configure.
- The OpenSCAD WASM distribution is large. Lazy-load it only after Generate is pressed and show the download size before fetching.
- Review the exact WASM package's license and source-distribution obligations before publishing. Do not assume an npm package's licensing is compatible merely because the original SCAD project is MIT.

## Delivery status

### Phase 1 — complete

- Guided choices
- URL/config sharing
- OpenSCAD preset and CLI export
- Existing viewer handoff

### Phase 2 — prototype complete

- Vendored OpenSCAD WASM worker
- Progress/cancel behavior
- Binary STL download
- Geometry validation and cache

The worker, validation, STL download, and source-versioned IndexedDB cache are
implemented. Changing the pinned source hash invalidates old cached artifacts.

### Phase 3 — 3MF complete; reusable schemas pending

- Dependency-free deterministic geometry-only 3MF writer
- Device/rack schema separated from this specific model
- Imported community device profiles with provenance and dimensional confidence
- Optional deploy-time pre-generation of popular configurations

## Acceptance checks before public use

- Every UI state maps to an explicit, versioned parameter set.
- Default browser output is byte-stable for the same source/runtime/parameters.
- Browser output matches the desktop production export within a documented mesh tolerance.
- Invalid and incompatible combinations cannot start a build.
- Generated STL passes closed-manifold and bounds checks.
- Generated 3MF opens in Bambu Studio, PrusaSlicer, and OrcaSlicer.
- Cancellation releases worker memory, and repeated builds do not grow memory without bound.

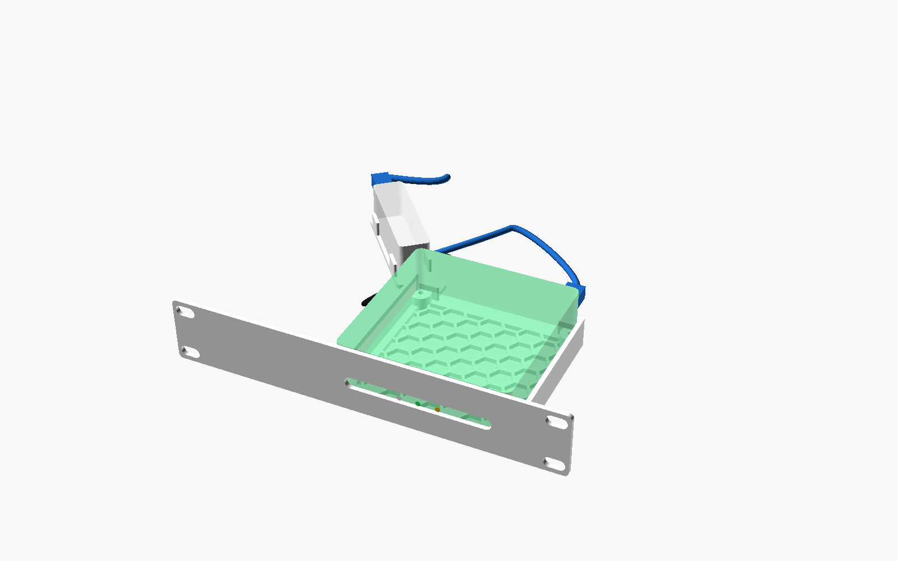
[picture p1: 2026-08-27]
renders/sicsolink_angled.png

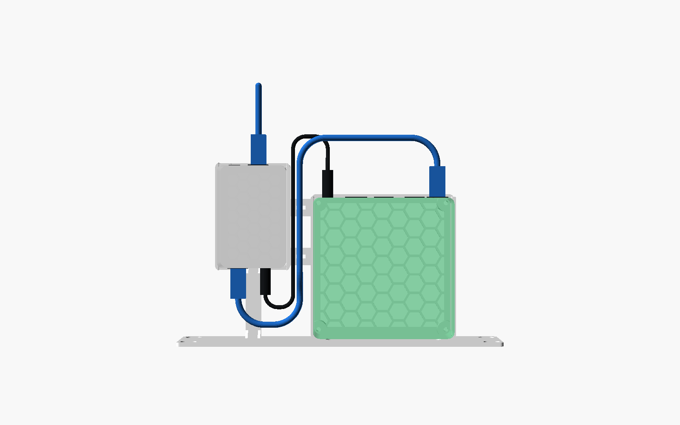
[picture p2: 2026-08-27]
renders/top.png

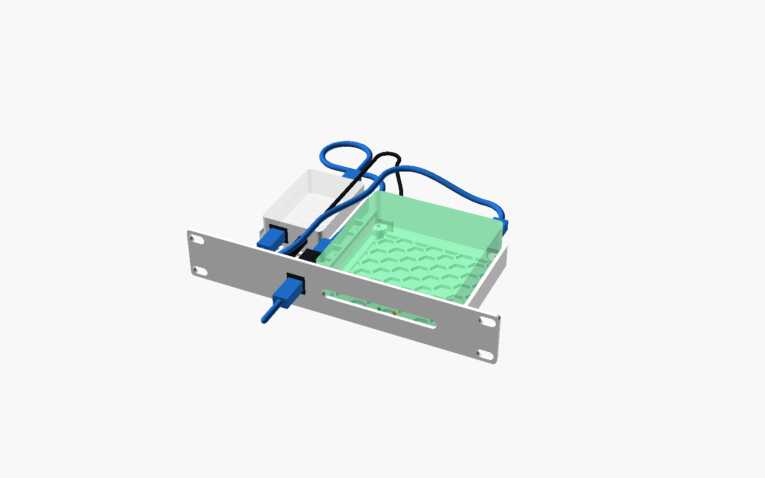
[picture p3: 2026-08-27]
renders/front_ethernet_right.png

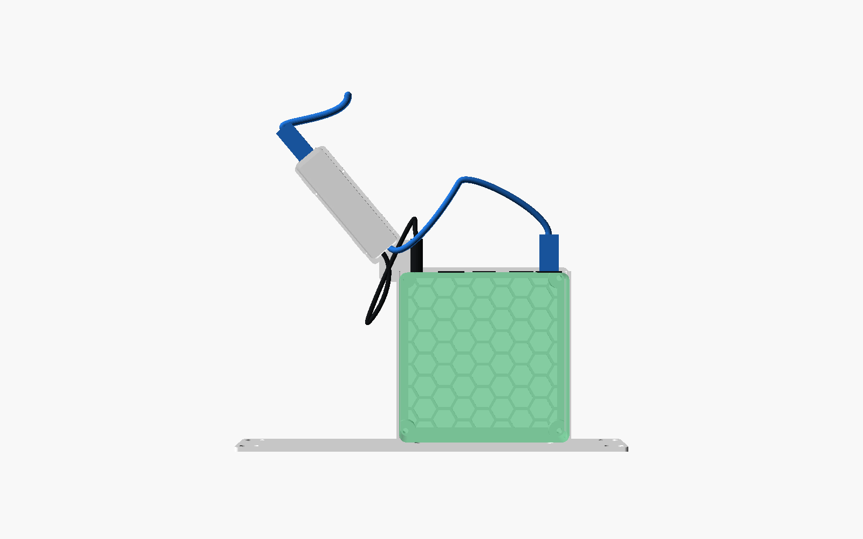
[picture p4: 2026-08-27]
renders/sicsolink_angled_top.png

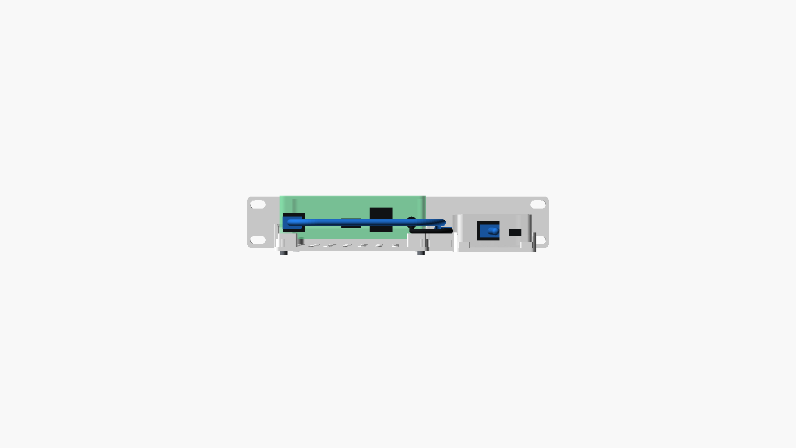
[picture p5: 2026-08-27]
renders/rear.png

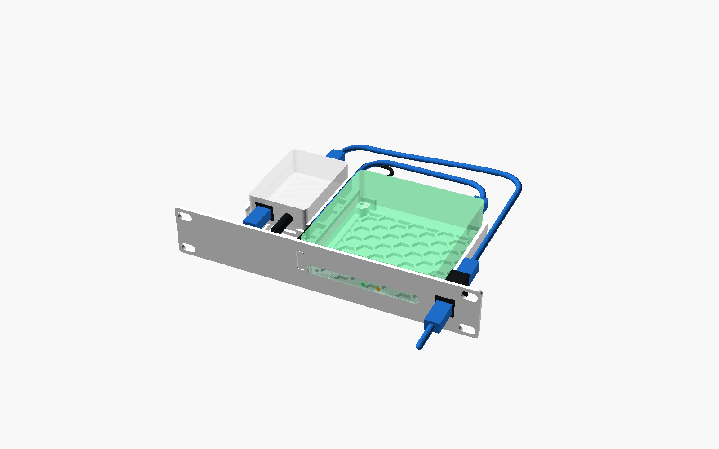
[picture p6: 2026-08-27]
renders/front_ethernet_far_right_with_shutter.png

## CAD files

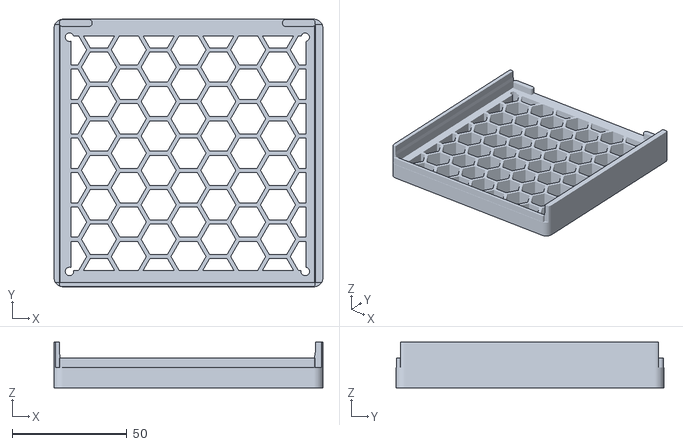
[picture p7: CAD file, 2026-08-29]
viewer/viewer_green_tray_friction_full.stl
117.1 x 116.6 x 20.0

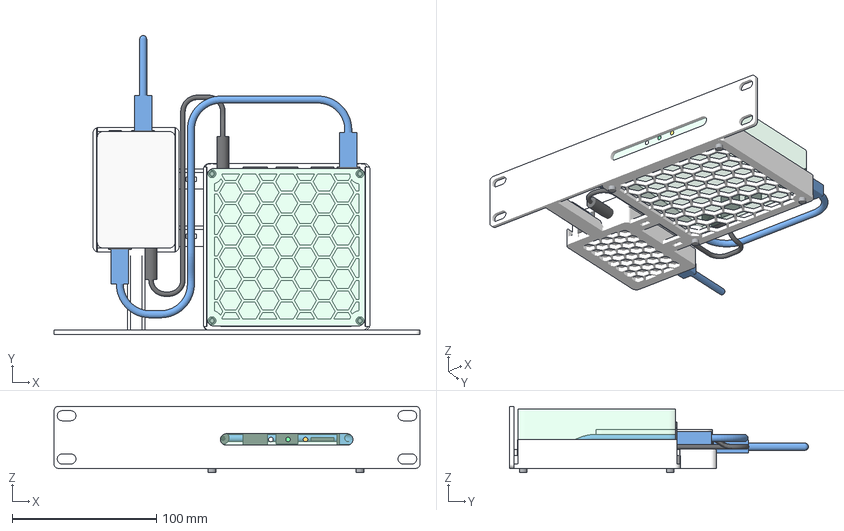
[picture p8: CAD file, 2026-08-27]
viewer/assembly_preview.3mf
254.0 x 207.5 x 46.0 mm

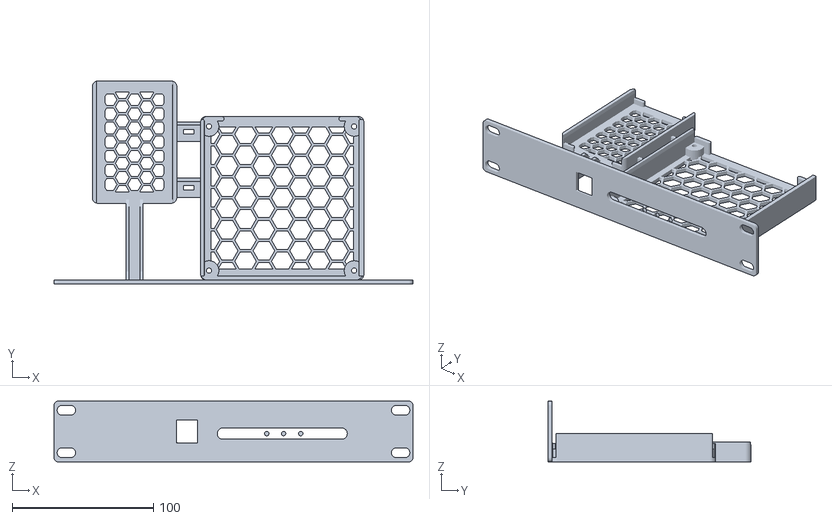
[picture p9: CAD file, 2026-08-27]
exports/assembly_front_ethernet.stl
254.0 x 143.7 x 43.0

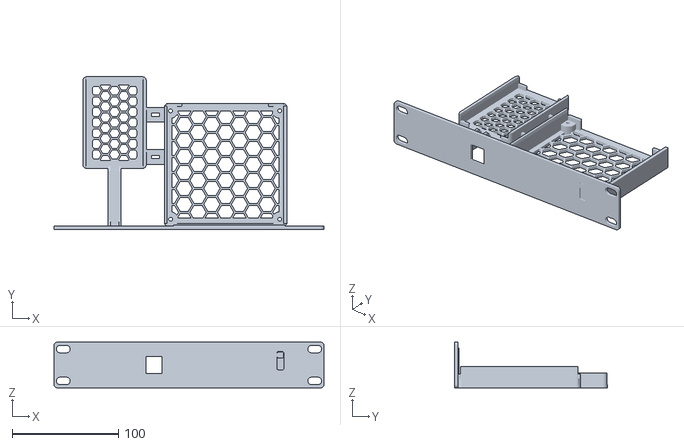
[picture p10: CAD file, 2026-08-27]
exports/assembly_front_ethernet_right_with_shutter.stl
254.0 x 143.7 x 43.0

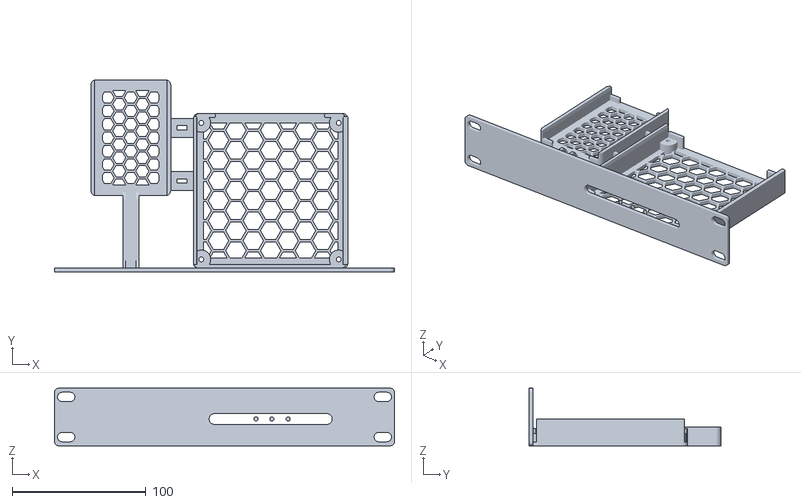
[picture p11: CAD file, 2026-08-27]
exports/assembly_with_logo.stl
254.0 x 143.7 x 43.0

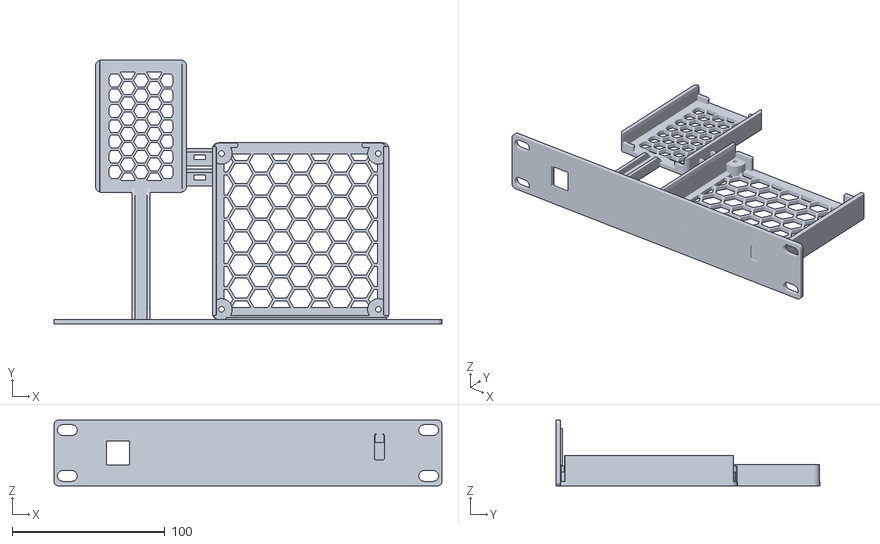
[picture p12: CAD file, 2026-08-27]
exports/assembly_front_ethernet_left_with_shutter.stl
254.0 x 172.7 x 43.0

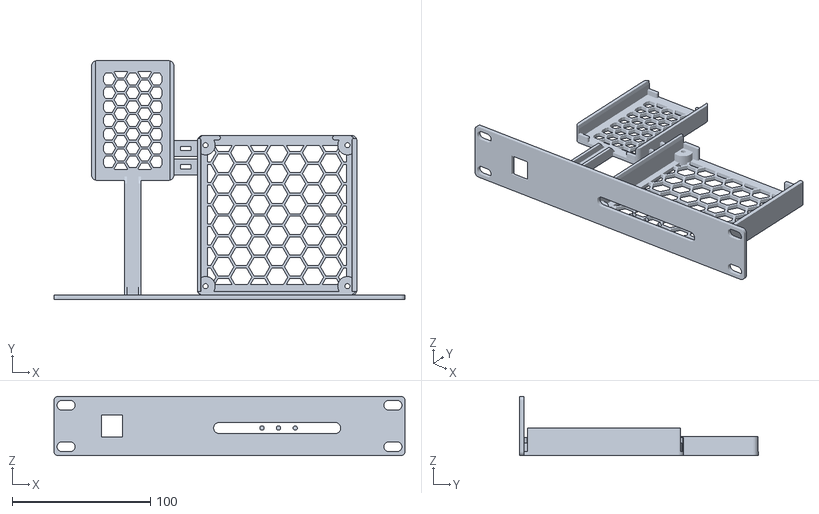
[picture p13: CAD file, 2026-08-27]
exports/assembly_front_ethernet_left.stl
254.0 x 172.7 x 43.0

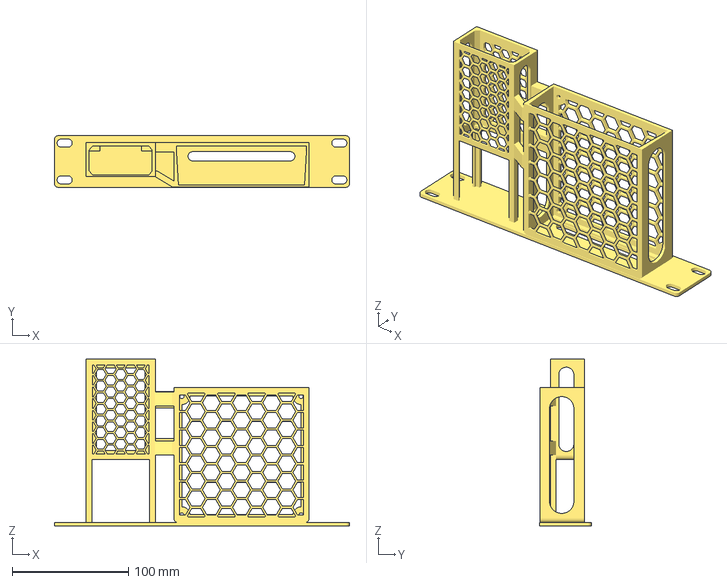
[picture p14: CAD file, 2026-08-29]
exports/one_piece_rear_cable_friendly_unified_frame_no_dovetail.3mf
254.0 x 44.5 x 143.7 mm

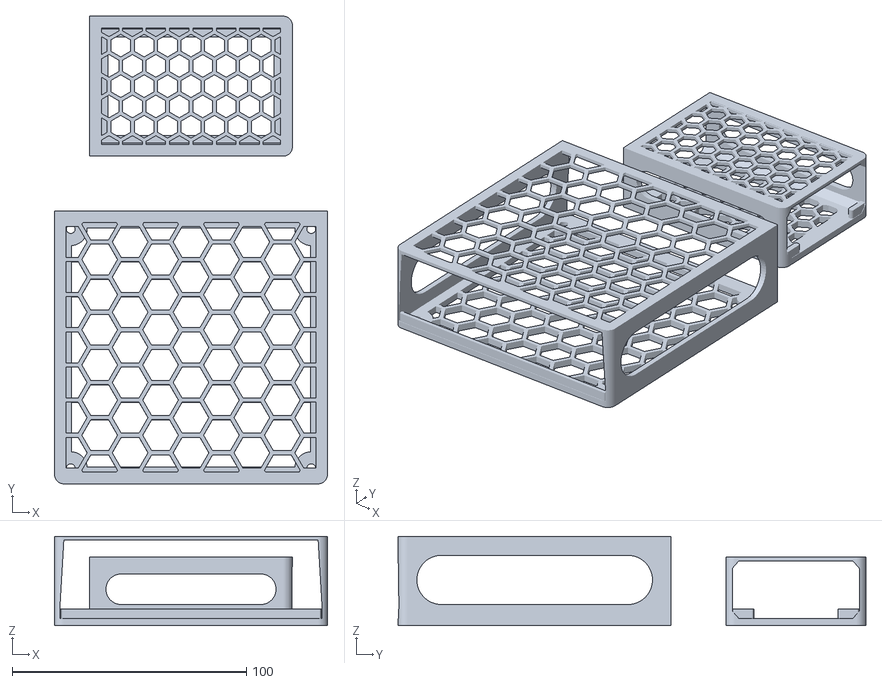
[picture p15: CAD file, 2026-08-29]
viewer/variants/stacked_center/viewer_retention_ventilated_sleeves.stl
116.5 x 199.6 x 38.0

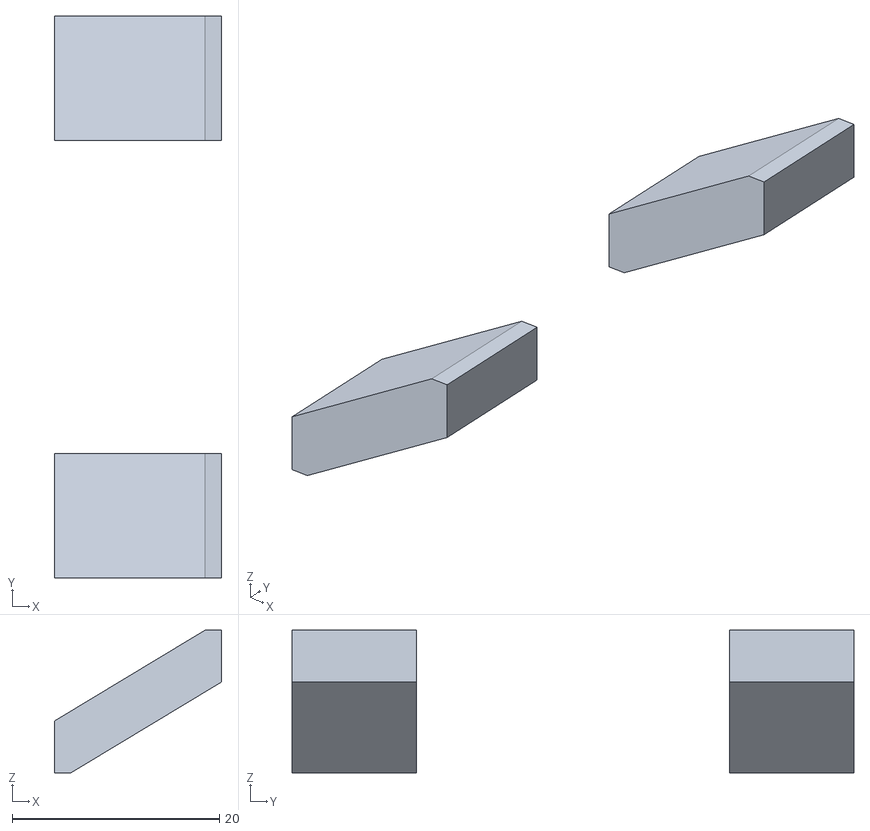
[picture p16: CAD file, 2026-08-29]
viewer/variants/unified_roof/viewer_unified_roof_cross_bridges.stl
16.2 x 54.3 x 13.8

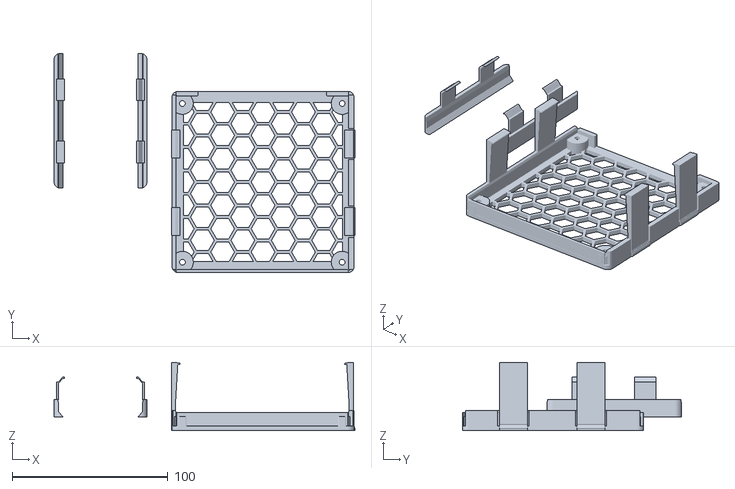
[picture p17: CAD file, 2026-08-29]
viewer/viewer_retention_hybrid_clips.stl
193.5 x 140.9 x 43.9

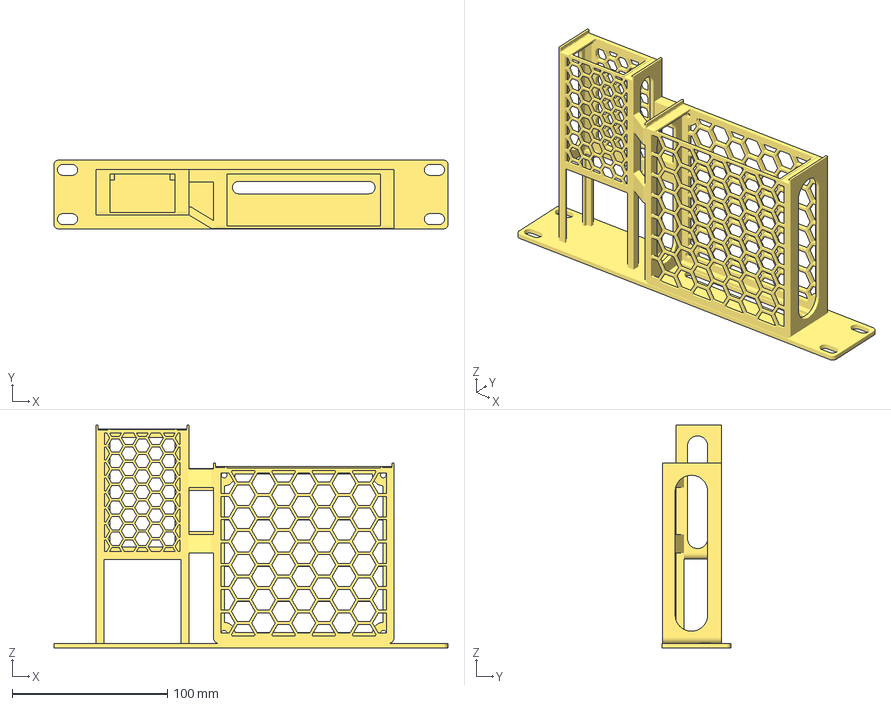
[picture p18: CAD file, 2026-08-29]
exports/one_piece_rear_cable_friendly_unified_frame_dovetail_ready.3mf
254.0 x 44.5 x 143.7 mm

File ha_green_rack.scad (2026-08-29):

/*
  Home Assistant Green + TP-Link TL-PD30G-M2
  10-inch / 1U rack mount for DeskPi RackMate T2

  Copyright (c) 2026 Richard Huang
  SPDX-License-Identifier: MIT

  Coordinate system:
    X = rack width
    Y = front-to-back depth
    Z = vertical

  Export by overriding `part`, for example:
    openscad -o exports/core.stl -D 'part="core"' ha_green_rack.scad
*/

$fn = 48;

// [assembly_preview, assembly, one_piece, one_piece_ventilated_sleeves, one_piece_ventilated_sleeves_print, one_piece_dovetail_ready, one_piece_dovetail_ready_print, dovetail_gates_plate, one_piece_logo_inlay, x2d_plate, x2d_plate_ventilated_sleeves, core, core_ventilated_sleeves, logo_inlay, left_ear, right_ear, led_insert, led_shutter, led_shutter_retainer, led_shutter_kit, led_fixed_window_kit, green_spacer, green_spacers_4x, fit_test, friction_fit_coupon, green_hybrid_clip_coupon, splitter_fit_coupon, splitter_hybrid_clip_coupon, hybrid_clip_coupon, green_vent_frame_coupon, splitter_vent_frame_coupon, vent_frame_coupon, dovetail_rail_coupon, green_dovetail_gate, splitter_dovetail_gate, keystone_fit_test, viewer_mount, viewer_mount_without_green_tray, viewer_splitter_floor, viewer_splitter_side_walls, viewer_splitter_end_stops, viewer_green_tray_standard, viewer_green_tray_friction, viewer_green_tray_friction_raised, viewer_green_tray_friction_full, viewer_green_tray_friction_pads, viewer_green_tray_friction_skeletal, viewer_insert, viewer_shutter_open, viewer_shutter_closed, viewer_shutter_retainer, viewer_logo, viewer_green, viewer_splitter, viewer_ports, viewer_green_ports, viewer_keystone_ports, viewer_data_cables, viewer_internal_data_cable, viewer_input_data_cable, viewer_dc_cable, viewer_fasteners, viewer_retention_factory_screws, viewer_retention_slide_latch, viewer_retention_corner_gate, viewer_retention_sled_gate, viewer_retention_padded_rails, viewer_retention_captive_strap, viewer_retention_x_cage, viewer_retention_hybrid_clips, viewer_retention_ventilated_sleeves, viewer_retention_dovetail_gates, viewer_retention_friction_sleeve, viewer_unified_roof_cross_bridges, viewer_enclosure_airframe, viewer_rulers, viewer_led_power, viewer_led_activity, viewer_led_health]
part = "assembly_preview";

// Production geometry uses the TP-Link. Viewer-only builds may override this
// with "sics" to show the user's existing captive-lead splitter.
splitter_model = "tplink";

// Viewer-only arrangement switch. The production files retain the selected
// cable-friendly side-by-side layout; "stacked_center" centers the Green and
// rotates the TP-Link across the rack directly behind it.
device_layout = "side_by_side";  // [side_by_side, unified_roof, stacked_center]
stacked_center_layout = device_layout == "stacked_center";
unified_roof_layout = device_layout == "unified_roof";

// Cable-friendly production layout: rear PoE/Ethernet entry with the TP-Link
// set back 60 mm from the face. Front-entry editions and other setbacks remain
// available as explicit build overrides.
front_ethernet_enabled = false;
front_keystone_side = "right";  // [left, right, far_right]

// Green support carried by the printable mount. The production default is a
// thin honeycomb deck raised directly to the device seating plane, eliminating
// separate riser columns. Legacy and comparison trays remain selectable.
green_tray_style = "friction_raised";  // [friction_raised, friction_pads, standard, friction_full, friction_skeletal]

// Physical front-window choice. When false, the face has no actuator slot,
// moving blade, or rear cartridge.
led_shutter_enabled = false;

// Leave the production LED window as a bare opening. Set true to add the
// optional self-retaining translucent insert without enabling the shutter.
led_window_insert_enabled = false;

// The production face is intentionally uninterrupted outside the LED
// window: no recessed logo, inlay pocket, or cosmetic seam. Set true only for
// an explicitly branded alternate export.
face_logo_enabled = false;

// Optional static-render aid. Browser GLBs carry all concepts and switch them
// interactively; leave this blank for normal production exports.
viewer_retention_preview = "";

// Device-fit tuning. Print fit_test.stl before the complete mount.
green_clearance = 0.50;       // clearance per side, mm
splitter_clearance = 0.40;    // clearance per side, mm

// Rack geometry
rack_width = 254.0;
rack_height = 44.45;          // exact IEC 60297 1U panel height
rack_unit_pitch = 44.45;      // nominal vertical allowance for 1U
rack_hole_spacing = 236.525;  // official RackMate T2 rail-hole pitch
rack_hole_x = (rack_width - rack_hole_spacing) / 2;
rack_hole_z = [6.35, 38.10];     // Mauker/EIA-style 1.25 in vertical pitch
rack_slot_w = 13.0;
rack_slot_h = 7.0;

// Split construction for the X2D bed
ear_width = 17.0;
core_width = rack_width - 2 * ear_width;
face_thickness = 3.0;
base_thickness = 3.0;

// Home Assistant publishes a 112 x 112 x 32 mm nominal envelope. Richard's
// physical enclosure measures 4 3/8 in (111.125 mm) across the bottom,
// 4 1/4 in (107.95 mm) across the top plateau after the inward taper, and
// 1 5/16 in (33.3375 mm) tall. The taper begins 1/4 in (6.35 mm) above
// the bottom. Treat both plan axes as square until a separate depth
// measurement says otherwise. Keep the published 112 mm value only as a
// documented conservative envelope; active fit geometry follows measurements.
// Centered placement preserves the previous LED window and screw pattern.
green_w = 111.125;
green_d = 111.125;
green_h = 33.3375;
green_top_w = 107.95;
green_top_d = 107.95;
green_published_envelope = 112.0;
green_cover_w = green_w;
green_cover_d = green_d;
green_lower_base_h = 5.0;
green_cover_relief_h = 2.0;
green_cover_side_clearance = 0.20;
green_cover_top_inset = (green_cover_w - green_top_w) / 2;
green_taper_start_h = 6.35;
green_cover_upper_bevel_h = green_h - green_taper_start_h;
green_inner_w = green_w + 2 * green_clearance;
green_inner_d = green_d + 2 * green_clearance;
green_mount_pitch_x = 102.65;
green_mount_pitch_y = 102.00;
green_mount_hole_d = 3.70;
green_spacer_od = 6.30;
green_spacer_bore = 3.35;
green_standoff_default = 6.025;
green_standoff_override = undef;
green_standoff = is_undef(green_standoff_override)
    ? green_standoff_default : green_standoff_override;
green_spacer_tip_h = 1.475;
green_spacer_h = green_standoff + green_spacer_tip_h;
// The normal layout moves the Green right to leave a full-depth splitter bay.
// The viewer-only stacked study centers it on the complete 254 mm panel.
green_x = stacked_center_layout
    ? core_width / 2 - green_w / 2
    : 88.0 + (112.0 - green_w) / 2;
green_y = 4.5 + (112.0 - green_d) / 2;
green_mount_x = [green_x + (green_w - green_mount_pitch_x) / 2,
                 green_x + (green_w + green_mount_pitch_x) / 2];
green_mount_y = [green_y + (green_d - green_mount_pitch_y) / 2,
                 green_y + (green_d + green_mount_pitch_y) / 2];
green_device_z = base_thickness + green_standoff;
unified_deck_raise = green_standoff;
unified_deck_z0 = green_device_z - base_thickness;
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

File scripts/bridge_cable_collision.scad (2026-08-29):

// Regression fixture: any exported geometry is an intersection between the
// side-by-side cage bridge and a modeled cable/plug envelope.
//
// Example:
//   openscad -o /tmp/bridge-cable-collision.stl \
//     -D 'part="__validation_only__"' \
//     scripts/bridge_cable_collision.scad

include <../ha_green_rack.scad>

intersection() {
    translate([ear_width, 0, 0]) union() {
        device_bridges();
        splitter_corner_l_ties_local();
        if (unified_roof_layout)
            unified_roof_cross_bridges_local();
    }
    union() {
        viewer_internal_data_cable();
        viewer_input_data_cable();
        viewer_dc_cable();
    }
}

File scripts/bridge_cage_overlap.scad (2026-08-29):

// Regression fixture: the lower box bridges must overlap both rounded cage
// floors by real volume so a production export cannot contain loose shells.

include <../ha_green_rack.scad>

intersection() {
    device_bridges();
    retention_ventilated_sleeves_local();
}

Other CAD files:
viewer/variants/stacked_center/viewer_green_tray_friction_full.stl
exports/assembly.stl
exports/assembly_with_shutter.stl
exports/assembly_front_ethernet_far_right.stl
exports/assembly_front_ethernet_far_right_with_shutter.stl
scripts/dovetail_slide_collision.scad
exports/assembly_legacy_screw_tray.stl
exports/core.stl
exports/core_front_ethernet.stl
exports/core_front_ethernet_left.stl
exports/core_front_ethernet_left_with_shutter.stl
exports/core_front_ethernet_right.stl
exports/core_front_ethernet_right_with_shutter.stl
exports/core_legacy_screw_tray.stl
exports/core_with_logo.stl
exports/core_with_shutter.stl
exports/dovetail_gates_optional_plate.3mf
exports/dovetail_gates_optional_plate.stl
exports/dovetail_rail_coupon.3mf
exports/dovetail_rail_coupon.stl
exports/fit_test.3mf
exports/fit_test.stl
exports/friction_fit_coupon.3mf
exports/friction_fit_coupon.stl
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

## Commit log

2026-08-27 Initial HA Green rack mount customizer
    [assembly.stl, assembly_front_ethernet.stl, assembly_front_ethernet_far_right.stl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]
2026-08-27 Use measured Home Assistant Green footprint
    [assembly.stl, assembly_front_ethernet.stl, assembly_front_ethernet_far_right.stl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]
2026-08-27 Add tighter Green friction-fit coupon
    [friction_fit_coupon.3mf, friction_fit_coupon.stl, ha_green_rack.scad]
2026-08-27 Add four-catch hybrid device retention prototype
    [green_hybrid_clip_coupon.3mf, green_hybrid_clip_coupon.stl, ha_green_rack.scad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]
2026-08-27 Reduce top-clip coupon material
    [green_hybrid_clip_coupon.3mf, green_hybrid_clip_coupon.stl, ha_green_rack.scad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]
2026-08-28 Align hybrid clips across viewer layouts
    [green_hybrid_clip_coupon.3mf, green_hybrid_clip_coupon.stl, ha_green_rack.scad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]
2026-08-28 Increase top-clip capture on both devices
    [green_hybrid_clip_coupon.3mf, green_hybrid_clip_coupon.stl, ha_green_rack.scad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]
2026-08-28 Smooth clips and integrate TP-Link wall tongues
    [green_hybrid_clip_coupon.3mf, green_hybrid_clip_coupon.stl, ha_green_rack.scad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]
2026-08-28 Extend hybrid clip overlap
    [green_hybrid_clip_coupon.3mf, green_hybrid_clip_coupon.stl, ha_green_rack.scad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]
2026-08-28 Fit TP-Link cradle to measured profile
    [ha_green_rack.scad, hybrid_clip_coupon.3mf, hybrid_clip_coupon.stl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]
2026-08-28 Add rigid catches and ventilated sleeve retention
    [ha_green_rack.scad, hybrid_clip_coupon.3mf, hybrid_clip_coupon.stl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]
2026-08-28 Lighten sleeve cages with open side bays
    [ha_green_rack.scad, viewer_retention_ventilated_sleeves.stl]
2026-08-28 Round and reinforce sleeve vent frames
    [ha_green_rack.scad, viewer_retention_ventilated_sleeves.stl]
2026-08-28 Use single rounded Green side vent
    [ha_green_rack.scad, viewer_retention_ventilated_sleeves.stl]
2026-08-28 Align rounded side frames with tray corners
    [ha_green_rack.scad, viewer_retention_ventilated_sleeves.stl]
2026-08-28 Make TP-Link enclosure profile symmetric
    [ha_green_rack.scad, viewer_retention_hybrid_clips.stl, viewer_retention_ventilated_sleeves.stl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]
2026-08-28 Align devices on a unified raised deck
    [core.stl, ha_green_rack.scad, one_piece_rear_cable_friendly_friction_pads_no_shutter_flat_face.3mf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]
2026-08-28 Add centered stacked layout and print-ready X2D plate
    [ha_green_rack.scad, one_piece.3mf, one_piece_rear_cable_friendly_friction_raised_no_shutter_flat_face.3mf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]
2026-08-28 Smooth TP-Link sleeve rear bevel walls
    [ha_green_rack.scad, viewer_retention_ventilated_sleeves.stl]
2026-08-28 Add measured Green cage fit coupons
    [fit_test.3mf, fit_test.stl, friction_fit_coupon.3mf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]
2026-08-28 Keep vent-frame cage below panel height
    [green_vent_frame_coupon.3mf, green_vent_frame_coupon.stl, ha_green_rack.scad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]
2026-08-28 Refine vent-frame cages and fit coupons
    [dovetail_rail_coupon.3mf, dovetail_rail_coupon.stl, green_vent_frame_coupon.3mf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]
2026-08-28 Slim vent-frame fit coupons
    [green_vent_frame_coupon.3mf, green_vent_frame_coupon.stl, ha_green_rack.scad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]
2026-08-28 Relax cage fits and recess dovetail gates
    [green_vent_frame_coupon.3mf, green_vent_frame_coupon.stl, ha_green_rack.scad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]
2026-08-28 Refine cage fits and make dovetail gates slideable
    [dovetail_rail_coupon.3mf, dovetail_rail_coupon.stl, dovetail_slide_collision.scad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]
2026-08-29 Add validated vent-frame production print
    [green_vent_frame_coupon.3mf, green_vent_frame_coupon.stl, ha_green_rack.scad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]
2026-08-29 Replace dovetail pads with straight contact beams
    [ha_green_rack.scad, viewer_retention_dovetail_gates.stl]
2026-08-29 Recess dovetail gates flush into cage walls
    [ha_green_rack.scad, viewer_retention_dovetail_gates.stl]
2026-08-29 Align recessed dovetail gates exactly flush
    [ha_green_rack.scad, viewer_retention_dovetail_gates.stl]
2026-08-29 Close top gaps above recessed dovetail gates
    [ha_green_rack.scad, viewer_retention_dovetail_gates.stl]
2026-08-29 Center LEDs and close dovetail roof seam
    [ha_green_rack.scad, one_piece_rear_cable_friendly_vent_frame_no_dovetail.3mf, one_piece_rear_cable_friendly_vent_frame_no_dovetail.stl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]
2026-08-29 Reinforce cage bridge for face-down printing
    [bridge_cable_collision.scad, ha_green_rack.scad, one_piece_rear_cable_friendly_vent_frame_no_dovetail.3mf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]
2026-08-29 Export optional dovetail-ready print set
    [dovetail_gates_optional_plate.3mf, dovetail_gates_optional_plate.stl, ha_green_rack.scad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]
2026-08-29 Replace triangular supports with hollow spine
    [ha_green_rack.scad, one_piece_rear_cable_friendly_vent_frame_dovetail_ready.3mf, one_piece_rear_cable_friendly_vent_frame_dovetail_ready.stl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]
2026-08-29 Tie splitter cage roof to faceplate
    [bridge_cable_collision.scad, ha_green_rack.scad, one_piece_rear_cable_friendly_vent_frame_dovetail_ready.3mf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]
2026-08-29 Make splitter face ties flush
    [ha_green_rack.scad, one_piece_rear_cable_friendly_vent_frame_dovetail_ready.3mf, one_piece_rear_cable_friendly_vent_frame_dovetail_ready.stl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]
2026-08-29 Replace center ties with corner L rails
    [bridge_cable_collision.scad, ha_green_rack.scad, one_piece_rear_cable_friendly_vent_frame_dovetail_ready.3mf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]
2026-08-29 Add raised PoE unified-roof viewer study
    [bridge_cable_collision.scad, ha_green_rack.scad, viewer_dc_cable.stl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]
2026-08-29 Tie unified cages at roof and floor
    [ha_green_rack.scad, viewer_unified_roof_cross_bridges.stl]
2026-08-29 Bottom-align unified cage frame
    [ha_green_rack.scad, viewer_dc_cable.stl, viewer_input_data_cable.stl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]
2026-08-29 Export print-ready unified cage frame
    [bridge_cage_overlap.scad, ha_green_rack.scad, one_piece_rear_cable_friendly_unified_frame_dovetail_ready.3mf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]
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
